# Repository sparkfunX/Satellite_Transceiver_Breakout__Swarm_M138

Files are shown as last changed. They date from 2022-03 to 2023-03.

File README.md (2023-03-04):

# Satellite Transceiver Breakout - Swarm M138

SparkFun Satellite Transceiver Kit - Swarm M138 (https://www.sparkfun.com/products/21287)

[*SparkFun Satellite Transceiver Kit - Swarm M138*](https://www.sparkfun.com/products/21287)

A breakout for the Swarm M138 satellite transceiver.

This breakout allows you to power and communicate with the Swarm M138 using USB 3 or USB-C, or breakout pins.

We've written a Python3 PyQt5 GUI to let you communicate with the modem. You will find it in its own dedicated repo:
- [**SparkFun Swarm M138 GUI**](https://github.com/sparkfun/SparkFun_Swarm_M138_GUI)

You will find the modem manual in the [**Documents**](./Documents) folder. It contains the full list of modem commands and messages.

You can also integrate the satellite transceiver directly into your project; the breakout pads can be used to provide power and access the 3.3V UART TX and RX signals.

Open the two split jumper pads on the bottom of the PCB first, located between the TXO/CH340_RXI and RXI/CH340_TXO pads. Then connect:
* GND to GND on your Arduino board
* VIN to 5V/V_USB on your Arduino board
* TXO to RX on your Arduino board (3.3V only!)
* RXI to TX on your Arduino board (3.3V only!)

Our [Swarm Satellite Arduino Library](https://github.com/sparkfun/SparkFun_Swarm_Satellite_Arduino_Library) makes communicating with the modem really easy.

## Repository Contents

- [**/Hardware**](./Hardware) - contains the Eagle PCB, SCH and LBR design files
- [**/Documents**](./Documents) - contains the datasheet etc. for the Swarm M138
- [**LICENSE.md**](./LICENSE.md) - contains the licence information

<br>

- [**SparkFun Swarm M138 GUI**](https://github.com/sparkfun/SparkFun_Swarm_M138_GUI) - dedicated repo for the Swarm M138 GUI

## Product Versions

- [KIT-21287](https://www.sparkfun.com/products/21287) - SparkFun Satellite Transceiver Kit - Swarm M138
- [SPX-19236](https://www.sparkfun.com/products/19236) - Original SparkX version

## License Information

This product is _**open source**_!

Please review the LICENSE.md file for license information.

If you have any questions or concerns on licensing, please contact technical support on our [SparkFun forums](https://forum.sparkfun.com/viewforum.php?f=123).

Distributed as-is; no warranty is given.

- Your friends at SparkFun.

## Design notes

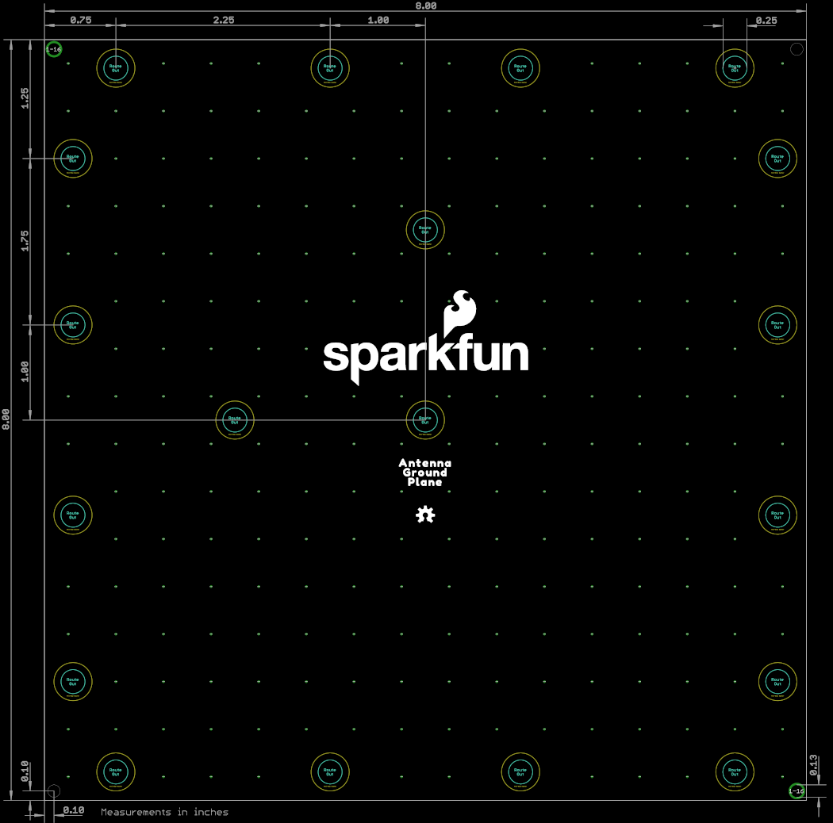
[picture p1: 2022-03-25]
Hardware/Ground Plate/Dimensions.png

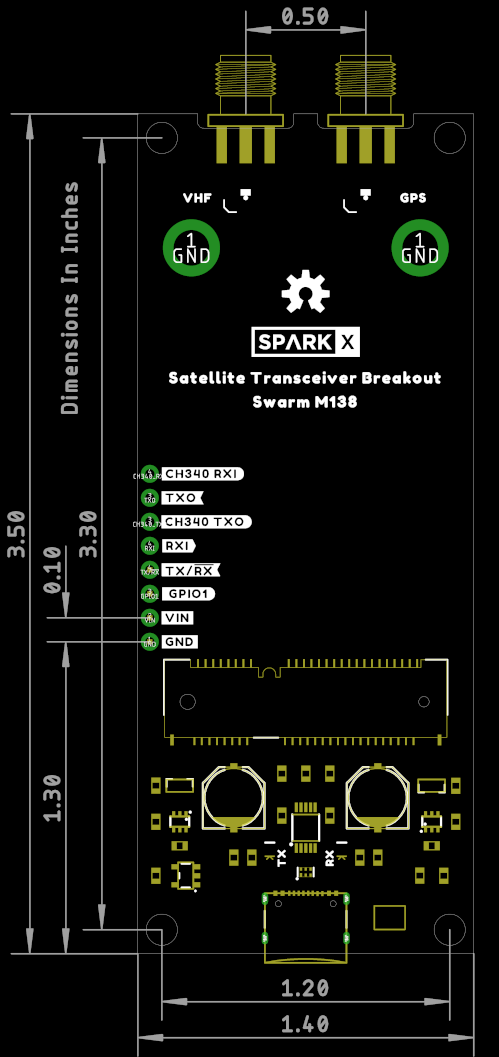
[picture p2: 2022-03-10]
img/Dimensions.png

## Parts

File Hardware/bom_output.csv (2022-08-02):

Qty | PROD_ID | Names | Value | Package
5 | CAP-08604 | C1; C2; C3; C7; C9 | 0.1uF | 0603
2 | CAP-12547 | C4; C5 | 100uF | PANASONIC_D
1 | CAP-11015 | C6 | 10uF | 0603
1 | CAP-13930 | C8 | 1.0uF | 0603
1 | CAP-00867 | C10 | 10nF | 0603
1 | DIO-14084 | D1 | PRTR5V0U2F | SOT886
1 | DIO-00821 | D2 | GREEN | LED-0603
1 | DIO-09003 | D3 | Yellow | LED-0603
1 | CONN-08289 | E1 | VHF | SMA-EDGE
1 | CONN-08289 | E2 | GPS | SMA-EDGE
1 | RES-14313 | F1 | 6V/2A | 1210
2 | CONN-09193 | GPS; VHF | U.FL | U.FL
2 | HW-16629 | H5; H6 | STAND-OFF-REFLOW-M2.5_1.5MM_TALL | STAND-OFF-REFLOW-M2.5
1 | CONN-14122 | J1 |  | USB-C-16P-2LAYER-PADS
1 | CONN-09696 | J2 |  | 1X04_NO_SILK
2 | TRANS-14386 | Q1; Q3 |  | SOT363_PHILIPS
2 | TRANS-14388 | Q2; Q4 | 20V/4.2A/52mΩ/1.4W | SOT23-3
2 | RES-12083 | R1; R2 | 5.1k | 0603
2 | RES-07863 | R3; R4 | 100 | 0603
4 | RES-07828 | R5; R6; R21; R23 | 100k | 0603
2 | RES-07868 | R22; R24 | 1M | 0603
1 | IC-14135 | U1 | CH340E_MSOP10 | MSOP10
1 | CONN-16558 | U2 | SWARM_M138_TRANSCEIVER_MAIN | M.2-SWARM-M138-A
1 | VREG-12457 | U3 | 3.3V | SOT23-5

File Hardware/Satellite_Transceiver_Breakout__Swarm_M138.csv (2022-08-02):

Part | Value | Device | Package | Description | DESIGNER | PROD_ID | REV | SF_ID | VALUE | Device Library | Device Library URN
BYP | JUMPER-SMT_2_NO_SILK | JUMPER-SMT_2_NO_SILK |  | Normally open jumper |  |  |  |  |  | SparkFun-Jumpers
C1 | 0.1uF | 0.1UF-0603-25V-5% |  | 0.1µF ceramic capacitors |  | CAP-08604 |  |  | 0.1uF | SparkFun-Capacitors
C2 | 0.1uF | 0.1UF-0603-25V-5% |  | 0.1µF ceramic capacitors |  | CAP-08604 |  |  | 0.1uF | SparkFun-Capacitors
C3 | 0.1uF | 0.1UF-0603-25V-5% |  | 0.1µF ceramic capacitors |  | CAP-08604 |  |  | 0.1uF | SparkFun-Capacitors
C4 | 100uF | 100UF-POLAR-25V-20%(ELEC) |  | 100µF polarized capacitors |  | CAP-12547 |  |  | 100uF | SparkFun-Capacitors
C5 | 100uF | 100UF-POLAR-25V-20%(ELEC) |  | 100µF polarized capacitors |  | CAP-12547 |  |  | 100uF | SparkFun-Capacitors
C6 | 10uF | 10UF-0603-6.3V-20% |  | 10.0µF ceramic capacitors |  | CAP-11015 |  |  | 10uF | SparkFun-Capacitors
C7 | 0.1uF | 0.1UF-0603-25V-5% |  | 0.1µF ceramic capacitors |  | CAP-08604 |  |  | 0.1uF | SparkFun-Capacitors
C8 | 1.0uF | 1.0UF-0603-16V-10%-X7R |  | 1µF ceramic capacitors |  | CAP-13930 |  |  | 1.0uF | SparkFun-Capacitors
C9 | 0.1uF | 0.1UF-0603-25V-5% |  | 0.1µF ceramic capacitors |  | CAP-08604 |  |  | 0.1uF | SparkFun-Capacitors
C10 | 10nF | 10NF-0603-50V-10% |  | 0.01uF/10nF/10,000pF ceramic capacitors |  | CAP-00867 |  |  | 10nF | SparkFun-Capacitors
D1 | PRTR5V0U2F | PRTR5V0U2F |  | A small ESD protection device. Most commonly used on USB D+/D- signals to protect large, expensive, or especially sensitive USB enabled devices. |  | DIO-14084 |  |  |  | SparkFun-IC-Power
D2 | GREEN | LED-GREEN0603 |  | Green SMD LED |  | DIO-00821 |  |  | GREEN | SparkFun-LED
D3 | Yellow | LED-YELLOW0603 |  | Yellow SMD LED |  | DIO-09003 |  |  | Yellow | SparkFun-LED
E1 | VHF | ANTENNA-SMA-GROUNDEDEDGE_SMA |  | SMA Antenna Connector w/ Ground |  | CONN-08289 |  |  |  | SparkFun-RF
E2 | GPS | ANTENNA-SMA-GROUNDEDEDGE_SMA |  | SMA Antenna Connector w/ Ground |  | CONN-08289 |  |  |  | SparkFun-RF
F1 | 6V/2A | PPTC_6V2A |  | Resettable Fuse PPTC |  | RES-14313 |  |  | 6V/2A | SparkFun-Fuses
FD1 | FIDUCIAL1X2 | FIDUCIAL1X2 |  | Fiducial Alignment Points |  |  |  |  |  | SparkFun-Aesthetics
FD2 | FIDUCIAL1X2 | FIDUCIAL1X2 |  | Fiducial Alignment Points |  |  |  |  |  | SparkFun-Aesthetics
FD3 | FIDUCIAL1X2 | FIDUCIAL1X2 |  | Fiducial Alignment Points |  |  |  |  |  | SparkFun-Aesthetics
FD4 | FIDUCIAL1X2 | FIDUCIAL1X2 |  | Fiducial Alignment Points |  |  |  |  |  | SparkFun-Aesthetics
FRAME1 | FRAME-LEDGER | FRAME-LEDGER |  | Schematic Frame - Ledger |  |  |  |  |  | SparkFun-Aesthetics
GND1 | GND | GND |  | Ground Supply Symbol |  |  |  |  |  | SparkFun-PowerSymbols
GND2 | GND | GND |  | Ground Supply Symbol |  |  |  |  |  | SparkFun-PowerSymbols
GND3 | GND | GND |  | Ground Supply Symbol |  |  |  |  |  | SparkFun-PowerSymbols
GND5 | GND | GND |  | Ground Supply Symbol |  |  |  |  |  | SparkFun-PowerSymbols
GND8 | GND | GND |  | Ground Supply Symbol |  |  |  |  |  | SparkFun-PowerSymbols
GND9 | GND | GND |  | Ground Supply Symbol |  |  |  |  |  | SparkFun-PowerSymbols
GND10 | GND | GND |  | Ground Supply Symbol |  |  |  |  |  | SparkFun-PowerSymbols
GND11 | GND | GND |  | Ground Supply Symbol |  |  |  |  |  | SparkFun-PowerSymbols
GND12 | GND | GND |  | Ground Supply Symbol |  |  |  |  |  | SparkFun-PowerSymbols
GND13 | GND | GND |  | Ground Supply Symbol |  |  |  |  |  | SparkFun-PowerSymbols
GND14 | GND | GND |  | Ground Supply Symbol |  |  |  |  |  | SparkFun-PowerSymbols
GND15 | GND | GND |  | Ground Supply Symbol |  |  |  |  |  | SparkFun-PowerSymbols
GND16 | GND | GND |  | Ground Supply Symbol |  |  |  |  |  | SparkFun-PowerSymbols
GND17 | GND | GND |  | Ground Supply Symbol |  |  |  |  |  | SparkFun-PowerSymbols
GND18 | GND | GND |  | Ground Supply Symbol |  |  |  |  |  | SparkFun-PowerSymbols
GND19 | GND | GND |  | Ground Supply Symbol |  |  |  |  |  | SparkFun-PowerSymbols
GND20 | GND | GND |  | Ground Supply Symbol |  |  |  |  |  | SparkFun-PowerSymbols
GND21 | GND | GND |  | Ground Supply Symbol |  |  |  |  |  | SparkFun-PowerSymbols
GND22 | GND | GND |  | Ground Supply Symbol |  |  |  |  |  | SparkFun-PowerSymbols
GND23 | GND | GND |  | Ground Supply Symbol |  |  |  |  |  | SparkFun-PowerSymbols
GND24 | GND | GND |  | Ground Supply Symbol |  |  |  |  |  | SparkFun-PowerSymbols
GND25 | GND | GND |  | Ground Supply Symbol |  |  |  |  |  | SparkFun-PowerSymbols
GND26 | GND | GND |  | Ground Supply Symbol |  |  |  |  |  | SparkFun-PowerSymbols
GND27 | GND | GND |  | Ground Supply Symbol |  |  |  |  |  | SparkFun-PowerSymbols
GND33 | GND | GND |  | Ground Supply Symbol |  |  |  |  |  | SparkFun-PowerSymbols
GND34 | GND | GND |  | Ground Supply Symbol |  |  |  |  |  | SparkFun-PowerSymbols
GND35 | GND | GND |  | Ground Supply Symbol |  |  |  |  |  | SparkFun-PowerSymbols
GND36 | GND | GND |  | Ground Supply Symbol |  |  |  |  |  | SparkFun-PowerSymbols
GND37 | GND | GND |  | Ground Supply Symbol |  |  |  |  |  | SparkFun-PowerSymbols
GPIO1 | JUMPER-SMT_3_1-NC_TRACE_SILK | JUMPER-SMT_3_1-NC_TRACE_SILK |  | Normally closed trace jumper (1 of 2 connections) |  |  |  |  |  | SparkFun-Jumpers
GPS | U.FL | U.FL2PIN |  | SMD Antenna Connector - U.FL |  | CONN-09193 |  | WRL-09144 | U.FL | SparkFun-Connectors
H1 | STAND-OFF | STAND-OFF |  | Stand Off |  |  |  |  |  | SparkFun-Hardware
H2 | STAND-OFF | STAND-OFF |  | Stand Off |  |  |  |  |  | SparkFun-Hardware
H3 | STAND-OFF | STAND-OFF |  | Stand Off |  |  |  |  |  | SparkFun-Hardware
H4 | STAND-OFF | STAND-OFF |  | Stand Off |  |  |  |  |  | SparkFun-Hardware
H5 | STAND-OFF-REFLOW-M2.5_1.5MM_TALL | STAND-OFF-REFLOW-M2.5_1.5MM_TALL |  | Stand Off Reflow Compatible |  | HW-16629 |  |  |  | SparkFun-Hardware
H6 | STAND-OFF-REFLOW-M2.5_1.5MM_TALL | STAND-OFF-REFLOW-M2.5_1.5MM_TALL |  | Stand Off Reflow Compatible |  | HW-16629 |  |  |  | SparkFun-Hardware
J1 |  | USB_C_2-LAYER_PADS |  | USB Type C 16Pin Connector |  | CONN-14122 |  |  |  | SparkFun-Connectors
J2 |  | CONN_041X04_NO_SILK |  | Multi connection point. Often used as Generic Header-pin footprint for 0.1 inch spaced/style header connections |  | CONN-09696 |  |  |  | SparkFun-Connectors
JP1 | USB_SOLDER_PADS | USB_SOLDER_PADS |  | Solder pad access to USB pins. Helpful to expose on PCBs so user can attach external USB connector if necessary. |  |  |  |  |  | SparkFun-Connectors
LOGO1 | SPECIAL_INSTRUCTIONS-ORDERING | SPECIAL_INSTRUCTIONS-ORDERING |  | Special Ordering/Production Instructions Alert |  |  |  |  |  | SparkFun-Aesthetics
LOGO2 | OSHW-LOGOM | OSHW-LOGOM |  | Open-Source Hardware (OSHW) Logo |  |  |  |  |  | SparkFun-Aesthetics
LOGO3 | OSHW-LOGOM | OSHW-LOGOM |  | Open-Source Hardware (OSHW) Logo |  |  |  |  |  | SparkFun-Aesthetics
Q1 |  | TRANS_PNP_DUALSOT-363 |  | Dual PNP Transistors in Single Package |  | TRANS-14386 |  |  |  | SparkFun-DiscreteSemi
Q2 | 20V/4.2A/52mΩ/1.4W | MOSFET_PCH-DMG2305UX-7 |  | P-channel MOSFETs |  | TRANS-14388 |  |  | 20V/4.2A/52mΩ/1.4W | SparkFun-DiscreteSemi
Q3 |  | TRANS_PNP_DUALSOT-363 |  | Dual PNP Transistors in Single Package |  | TRANS-14386 |  |  |  | SparkFun-DiscreteSemi
Q4 | 20V/4.2A/52mΩ/1.4W | MOSFET_PCH-DMG2305UX-7 |  | P-channel MOSFETs |  | TRANS-14388 |  |  | 20V/4.2A/52mΩ/1.4W | SparkFun-DiscreteSemi
R1 | 5.1k | 5.1KOHM5.1KOHM-0603-1/10W-1% |  |  |  | RES-12083 |  |  | 5.1k | SparkFun-Resistors
R2 | 5.1k | 5.1KOHM5.1KOHM-0603-1/10W-1% |  |  |  | RES-12083 |  |  | 5.1k | SparkFun-Resistors
R3 | 100 | 100OHM-0603-1/10W-1% |  | 100Ω resistor |  | RES-07863 |  |  | 100 | SparkFun-Resistors
R4 | 100 | 100OHM-0603-1/10W-1% |  | 100Ω resistor |  | RES-07863 |  |  | 100 | SparkFun-Resistors
R5 | 100k | 100KOHM-0603-1/10W-1% |  | 100kΩ resistor |  | RES-07828 |  |  | 100k | SparkFun-Resistors
R6 | 100k | 100KOHM-0603-1/10W-1% |  | 100kΩ resistor |  | RES-07828 |  |  | 100k | SparkFun-Resistors
R21 | 100k | 100KOHM-0603-1/10W-1% |  | 100kΩ resistor |  | RES-07828 |  |  | 100k | SparkFun-Resistors
R22 | 1M | 1MOHM-0603-1/4W-5% |  | 1MΩ resistor |  | RES-07868 |  |  | 1M | SparkFun-Resistors
R23 | 100k | 100KOHM-0603-1/10W-1% |  | 100kΩ resistor |  | RES-07828 |  |  | 100k | SparkFun-Resistors
R24 | 1M | 1MOHM-0603-1/4W-5% |  | 1MΩ resistor |  | RES-07868 |  |  | 1M | SparkFun-Resistors
RXI | JUMPER-COMBO_2_NC_TRACE | JUMPER-COMBO_2_NC_TRACE |  |  |  |  |  |  |  | SparkFun-Jumpers
RX_LED | JUMPER-SMT_2_NC_TRACE_SILK | JUMPER-SMT_2_NC_TRACE_SILK |  | Normally closed trace jumper |  |  |  |  |  | SparkFun-Jumpers
SUPPLY1 | V_USB | V_USB |  | USB Voltage Supply |  |  |  |  |  | SparkFun-PowerSymbols
SUPPLY2 | V_USB_2 | V_USB_2 |  | USB Voltage Supply |  |  |  |  |  | SparkFun-PowerSymbols
SUPPLY4 | V_USB_2 | V_USB_2 |  | USB Voltage Supply |  |  |  |  |  | SparkFun-PowerSymbols
SUPPLY5 | VIN | VIN |  | Input Voltage Supply |  |  |  |  |  | SparkFun-PowerSymbols
SUPPLY7 | VIN | VIN |  | Input Voltage Supply |  |  |  |  |  | SparkFun-PowerSymbols
SUPPLY8 | V_USB | V_USB |  | USB Voltage Supply |  |  |  |  |  | SparkFun-PowerSymbols
SUPPLY9 | VCC | VCC |  | VCC Voltage Supply |  |  |  |  |  | SparkFun-PowerSymbols
SUPPLY10 | VCC | VCC |  | VCC Voltage Supply |  |  |  |  |  | SparkFun-PowerSymbols
SUPPLY11 | VCC | VCC |  | VCC Voltage Supply |  |  |  |  |  | SparkFun-PowerSymbols
SUPPLY12 | VCC | VCC |  | VCC Voltage Supply |  |  |  |  |  | SparkFun-PowerSymbols
SUPPLY14 | VCC | VCC |  | VCC Voltage Supply |  |  |  |  |  | SparkFun-PowerSymbols
SUPPLY15 | VCC | VCC |  | VCC Voltage Supply |  |  |  |  |  | SparkFun-PowerSymbols
SUPPLY16 | VIN | VIN |  | Input Voltage Supply |  |  |  |  |  | SparkFun-PowerSymbols
SUPPLY17 | 3.3V | 3.3V |  | 3.3V Supply Symbol |  |  |  |  |  | SparkFun-PowerSymbols
SUPPLY18 | 3.3V | 3.3V |  | 3.3V Supply Symbol |  |  |  |  |  | SparkFun-PowerSymbols
SUPPLY19 | 3.3V | 3.3V |  | 3.3V Supply Symbol |  |  |  |  |  | SparkFun-PowerSymbols
SUPPLY20 | V_USB_2 | V_USB_2 |  | USB Voltage Supply |  |  |  |  |  | SparkFun-PowerSymbols
SUPPLY21 | V_USB_2 | V_USB_2 |  | USB Voltage Supply |  |  |  |  |  | SparkFun-PowerSymbols
SUPPLY27 | VCC | VCC |  | VCC Voltage Supply |  |  |  |  |  | SparkFun-PowerSymbols
SUPPLY29 | VCC | VCC |  | VCC Voltage Supply |  |  |  |  |  | SparkFun-PowerSymbols
SUPPLY31 | VCC | VCC |  | VCC Voltage Supply |  |  |  |  |  | SparkFun-PowerSymbols
TXO | JUMPER-COMBO_2_NC_TRACE | JUMPER-COMBO_2_NC_TRACE |  |  |  |  |  |  |  | SparkFun-Jumpers
TX_LED | JUMPER-SMT_2_NC_TRACE_SILK | JUMPER-SMT_2_NC_TRACE_SILK |  | Normally closed trace jumper |  |  |  |  |  | SparkFun-Jumpers
U$1 | SPARKX-LOGO5 | SPARKX-LOGO5 |  |  |  |  |  |  |  | SparkX
U$2 | SPARKX-LOGO5 | SPARKX-LOGO5 |  |  |  |  |  |  |  | SparkX
U1 | CH340E_MSOP10 | CH340E_MSOP10 |  |  |  | IC-14135 |  |  |  | SparkFun-IC-Comms
U2 | SWARM_M138_TRANSCEIVER_MAIN | SWARM_M138_TRANSCEIVER_MAIN |  | Swarm M138 Modem |  | CONN-16558 |  |  |  | SparkFun-RF
U3 | 3.3V | V_REG_AP2112K-3.3V |  | AP2112 - 600mA CMOS LDO Regulator w/ Enable |  | VREG-12457 |  |  | 3.3V | SparkFun-IC-Power
VCC | TEST-POINT3X5 | TEST-POINT3X5 |  | SparkFun Test Points |  |  |  |  |  | SparkFun-Connectors
VHF | U.FL | U.FL2PIN |  | SMD Antenna Connector - U.FL |  | CONN-09193 |  | WRL-09144 | U.FL | SparkFun-Connectors

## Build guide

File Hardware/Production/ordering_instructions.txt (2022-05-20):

panel size, 158x113mm
PCB thickness, 1.6mm
number of layers, 2
soldermask color, Black
silkscreen color, White
oz copper, 1oz
finish, HASL lead free
stencils, top
pcs per panel, 4
min trace width, 0.1524mm / 0.0060in
min drill size, 0.3000mm / 0.0118in

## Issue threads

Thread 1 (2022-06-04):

Example Sketch Request - 'Live' Data Uplink

K4KDR, 2022-06-04:
The M138 is working spectacularly well - way beyond my expectations.  Thanks to all involved.

The Arduino examples are very helpful.  There are examples on how to transmit static text or hex strings as well as examples on how to perform essentially 'Serial Console' type interactions with the M138.

Would it be possible to see an example that illustrates how the M138 will probably be most commonly used:  to **upload sensor data on a periodic (i.e., once per hour) basis?**   I am referring to analog sensors (air temperature, for example) that would be connected to one of the Arduino's input pins and on a periodic basis, the most current 'live' value uploaded via satellite.

In fact, I have already heard from one person tasked with with monitoring environmental data in an EXTREMELY remote location and naturally he is very interested in your product & the SWARM service.  However, while I already use Arduino devices to uplink that kind of data via other LoRa hats as well as via the local IP network, I'm not clear how to submit a 'live' value on a scheduled basis for upload via the M138. (I realize messages have to be queued, so the telemetry won't be EXACTLY live... just looking to acquire the current value once per hour for submission to the uplink queue)

Thanks in advance for any guidance on this!

-Scott,  K4KDR

PaulZC, 2022-06-04:
Hi Scott,

Assuming you want to send your sensor data in text format, the critical lines of code are these:

https://github.com/sparkfun/SparkFun_Swarm_Satellite_Arduino_Library/blob/b2a912294154c3e5fa0529661527b384e36c3efe/examples/Example14_transmitText/Example14_transmit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

```mySwarm.transmitText``` is the function which adds the message (contained in the ```myMessage``` char array) to the modem's transmit queue.

If you wanted to, you could include the local time or modem time in the message itself (together with your sensor data). That way, you would know the time the readings were taken, rather than the time the message was transmitted / delivered etc..

There are many ways of 'triggering' the transmit once per hour. Using Arduino ```millis()``` is the simplest. The code would look something like:

```
static unsigned long lastTransmit;

if (millis() > (lastTransmit + 3600000)) // Transmit once per hour
{
  lastTransmit = millis(); // Update lastTransmit
  uint64_t id;
  char myMessage[192];
  // Add your own code here to put your sensor readings into myMessage in text format
  // Add a 'null' (zero) to mark the end of the data
  Swarm_M138_Error_e err = mySwarm.transmitText((const char *)myMessage, &id);
  // Do something with id here - with you want to
}
```

Is that the kind of thing you are looking for?

Best wishes,
Paul

K4KDR, 2022-06-04:
Thank you for the reply!

My concern from the examples was that the setting of the upload string was static & then the code just listened for opportunities to transmit when a satellite was heard:

```
void loop()
{
  mySwarm.checkUnsolicitedMsg();
}
```

... so, the analog value could get old and was never updated.   It looks like your new code:

```
if (millis() > (lastTransmit + 3600000)) // Transmit once per hour
{
  lastTransmit = millis(); // Update lastTransmit
  uint64_t id;
  char myMessage[192];
  // Add your own code here to put your sensor readings into myMessage in text format
  // Add a 'null' (zero) to mark the end of the data
  Swarm_M138_Error_e err = mySwarm.transmitText((const char *)myMessage, &id);
  // Do something with id here - if you want to
}
```

... will take care of that nicely.  Can't wait to test it out.  Thanks very much!!

PaulZC, 2022-06-04:
Hi Scott,

The examples are a bit 'cluttered'. My bad...

Let me try and simplify the transmit message process:

As we discussed above, you queue a message for transmission using ```mySwarm.transmitText``` (or ```mySwarm.transmitBinary``` ). Once the message is in the transmit queue, the modem will transmit it on the next satellite pass - without needing any further intervention. All you need to do is keep the modem powered on and awake.

There are two ways to tell if your message has been transmitted. You can:
* Check how many messages are in the transmit queue with ```getUnsentMessageCount```
  * When this returns to zero, you know all messages have been sent
* Or wait for the unsolicited ```$TD SENT``` to arrive
  * A ```$TD SENT``` message is generated each time a message is sent
  * It contains the ```msg_ID``` of the message that has just been sent plus other information about the signal strength etc.

You can manually poll the unsent message count as often as you want to.

If you want to make use of the ```$TD SENT``` message, then you need to:
* Set up a callback for it - with ```setTransmitDataCallback```
* Call ```checkUnsolicitedMsg``` often

The callback is called as soon as ```checkUnsolicitedMsg``` 'intercepts' the ```$TD SENT```.

If you unpick the examples a bit, you will find that they show: how to do things manually; and how to use callbacks to help.

E.g. for the GPS Geospatial Information:
* You can request (poll) the geospatial information manually using [getGeospatialInfo](https://github.com/sparkfun/SparkFun_Swarm_Satellite_Arduino_Library/blob/b2a912294154c3e5fa0529661527b384e36c3efe/examples/Example5_GeospatialInformation/Example5_G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)
* And/or you can:
  * Set up a [callback for the $GN message](https://github.com/sparkfun/SparkFun_Swarm_Satellite_Arduino_Library/blob/b2a912294154c3e5fa0529661527b384e36c3efe/examples/Example5_GeospatialInformation/Example5_G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)
  * Enable [unsolicited $GN messages](https://github.com/sparkfun/SparkFun_Swarm_Satellite_Arduino_Library/blob/b2a912294154c3e5fa0529661527b384e36c3efe/examples/Example5_GeospatialInformation/Example5_G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) at your desired rate/interval
  * Call [checkUnsolicitedMsg](https://github.com/sparkfun/SparkFun_Swarm_Satellite_Arduino_Library/blob/b2a912294154c3e5fa0529661527b384e36c3efe/examples/Example5_GeospatialInformation/Example5_G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) often
  * The [callback](https://github.com/sparkfun/SparkFun_Swarm_Satellite_Arduino_Library/blob/b2a912294154c3e5fa0529661527b384e36c3efe/examples/Example5_GeospatialInformation/Example5_G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) is called when a $GN message arrives

One final piece of advice: once an unsolicited messages is enabled, you have to [un-enable it](https://github.com/sparkfun/SparkFun_Swarm_Satellite_Arduino_Library/blob/b2a912294154c3e5fa0529661527b384e36c3efe/examples/Example18_DisableUnsolicitedMessages/Exam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) to stop it being produced. The modem remembers which unsolicited messages are enabled, even when power-cycled. The only one you cannot disable is ```$TD SENT```.

Have fun!
Paul

K4KDR, 2022-06-05:
Thanks again for all the help - much appreciated!!

An update:  https://twitter.com/scott23192/status/1533526372768960512

PaulZC, 2022-06-09:
Linking this to issue 21 in the Library repo. That's also a request for a data uplink example:

https://github.com/sparkfun/SparkFun_Swarm_Satellite_Arduino_Library/issues/21

Closed 2022-06-04.

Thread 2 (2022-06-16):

5v Logic Tolerance?

K4KDR, 2022-06-16:
Since I have to think that I won't be the last person to make this mistake, a question please...

Wanting to test 'Sleep' Mode with the Arduino device connected to my M138, I found that the Arduino Due that I had was not supported by the same **avr/sleep.h** library that is most commonly used.  So, I purchased a couple of MEGA boards to use with the M138 to allow me to experiment with Sleep mode.

However, for several minutes after connecting one of the hardware serial UART connections from the MEGA to the M138, I forgot about the M138's requirement for 3.3v logic levels.  During that time, a message was queued and things appeared to work normally.  However, I immediately disconnected power from both devices and am in the process of wiring up a logic level shifter board between the MEGA & the M138.

Does the M138 have (I hope) "some" tolerance to the presence of a 5v logic level on the serial RX/TX pins?    Fingers crossed that all is well when I re-wire with the 5v/3.3v level shifter in place.

Thanks!

-Scott,  K4KDR

PaulZC, 2022-06-16:
Hi Scott,

This is (probably) a case of "you've got away with it". It is normal for microcontrollers to have protection diodes on their IO pins. If the pin voltage is taken above VCC (3.3V) the diode starts dumping current from the pin to the VCC rail. They're there to cope with brief over-voltage (ESD-like) events. Also the IO (UART) pins on the MEGA will only be able to deliver limited current. Put those two things together and your're _**probably**_ OK.

Proper level-shifters are the best way to go.

I don't know what the quiescent current draw of the MEGA board will be with the processor in sleep. It is probably still quite high. There's a bunch of stuff on there that will keep drawing current even if the processor isn't. If you really want to get the sleep current right down, you need a board that has been designed for it. Our [OpenLog Artemis](https://www.sparkfun.com/products/19426) was designed that way. Take a look at Unexpected Maker's boards too - he's doing great things with the sleep current.

Best wishes,
Paul

PaulZC, 2022-06-16:
Closing...

K4KDR, 2022-06-16:
Thanks so much for the VERY informative reply!   I will certainly check out those other boards.

Yes, now that everything is powered back up with level shifters on all connections, everything seems fine.  Serial Monitor feedback is all correct & messages are uploading via satellite.

Thanks again!

Closed 2022-06-16.

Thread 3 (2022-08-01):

BOM

tremmert81, 2022-08-01:
Is it possible for you to upload the BOM?  I am not finding anything in this repository..

PaulZC, 2022-08-02:
Hi @tremmert81 ,

If you download the free version of Eagle, you can open the hardware files and create the BOM for yourself. But - to save you some time - I've added a couple of different versions to the [Hardware folder](https://github.com/sparkfunX/Satellite_Transceiver_Breakout__Swarm_M138/tree/main/Hardware).

Best wishes,
Paul

Closed 2022-08-02.

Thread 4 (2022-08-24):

M138 Absolute VCC

jacky4566, 2022-08-24:
What is the absolute VCC for the M138?
The datasheet says 5.0V and SparkFun schematic shows this connected directly to USB which is allowed to deviate up to 5.5V

Could be a problem?

PaulZC, 2022-08-25:
Hello Jackson (@jacky4566 ),

The latest M138 datasheet quotes an input voltage of 3.0V to 5.0V. It also quotes absolute limits of 3.0V to 5.0V, which is unusual.

However, an earlier version of the datasheet - the one we were working from when we designed the board - quoted an input voltage range and absolute limits of 3.0V to 5.5V.

I believe the USB voltage requirement is 5.0V +/- 5%. I.e. 5.25V maximum? I believe the +0.5V deviation only applies during transitions (i.e. at switch-on)?

In summary, I believe we're OK, but I will check.

Best wishes,
Paul

PaulZC, 2022-08-26:
Hi Jackson,

We've been in touch with Swarm and they've confirmed that the modem can withstand 5.5V, as an _absolute_ maximum (non-continuous). Regular operation should be between 3.0V and 5.0V.

Best wishes,
Paul

Closed 2022-08-26.

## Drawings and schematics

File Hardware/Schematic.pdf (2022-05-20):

# VBUS CC1 D+D- CC2 SHLD

## Design by: USB⁻C

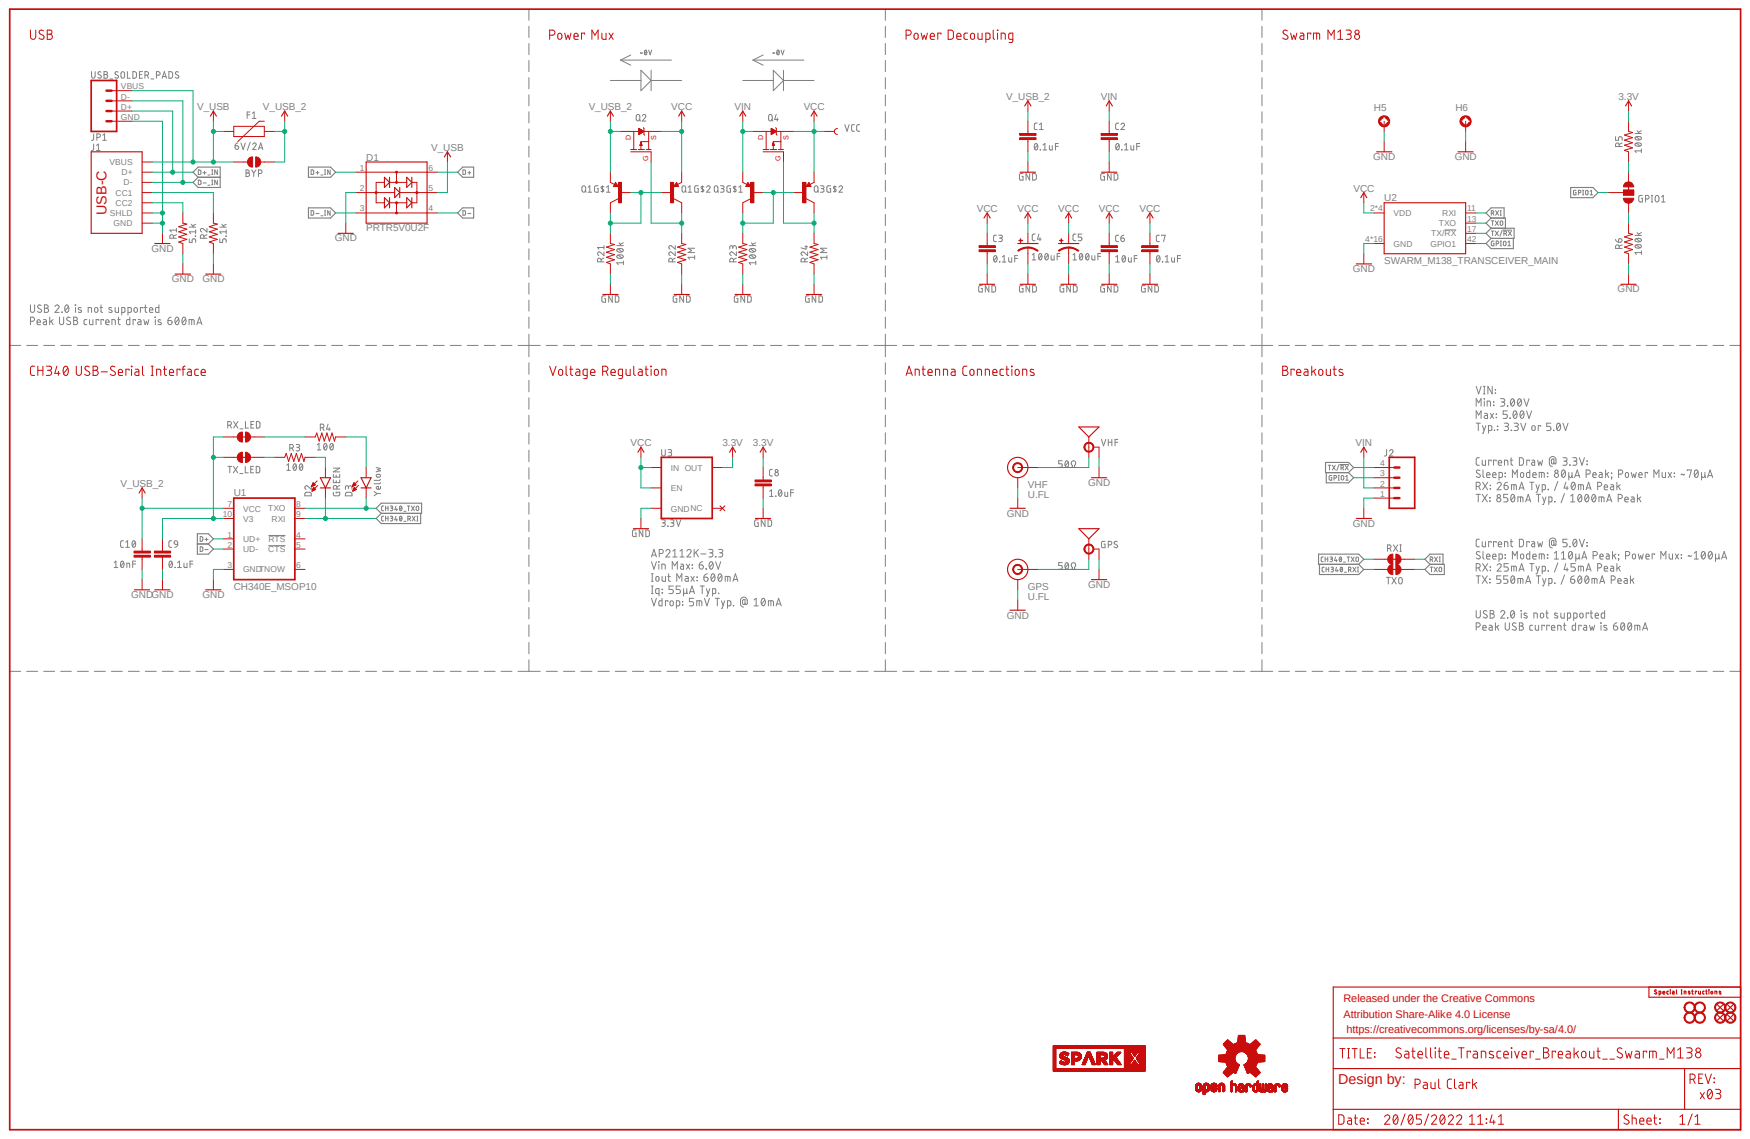
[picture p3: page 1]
GND GND; GND; PRTR5V0U2F; V_USB; VCC; CH340E_MSOP10 GNDGND; VIN; SWARM_M138_TRANSCEIVER_MAIN; V_USB_2; V_USB_2 GND; CTS; 5 RTS; 4 GND 3; TNOW; 6 RXI; 9 TXO; VCC 7 U1; VHF GPS; H6 GND 4*16 VDD 2*4; RXI 11 TX/RX 17 TXO 13 GPIO1 42 U2; INGNDOUT EN; VBUS D- D+GND

GND
U.FL U.FL GND

Released under the Creative Commons
Attribution Share-Alike 4.0 License
https://creativecommons.org/licenses/by-sa/4.0/

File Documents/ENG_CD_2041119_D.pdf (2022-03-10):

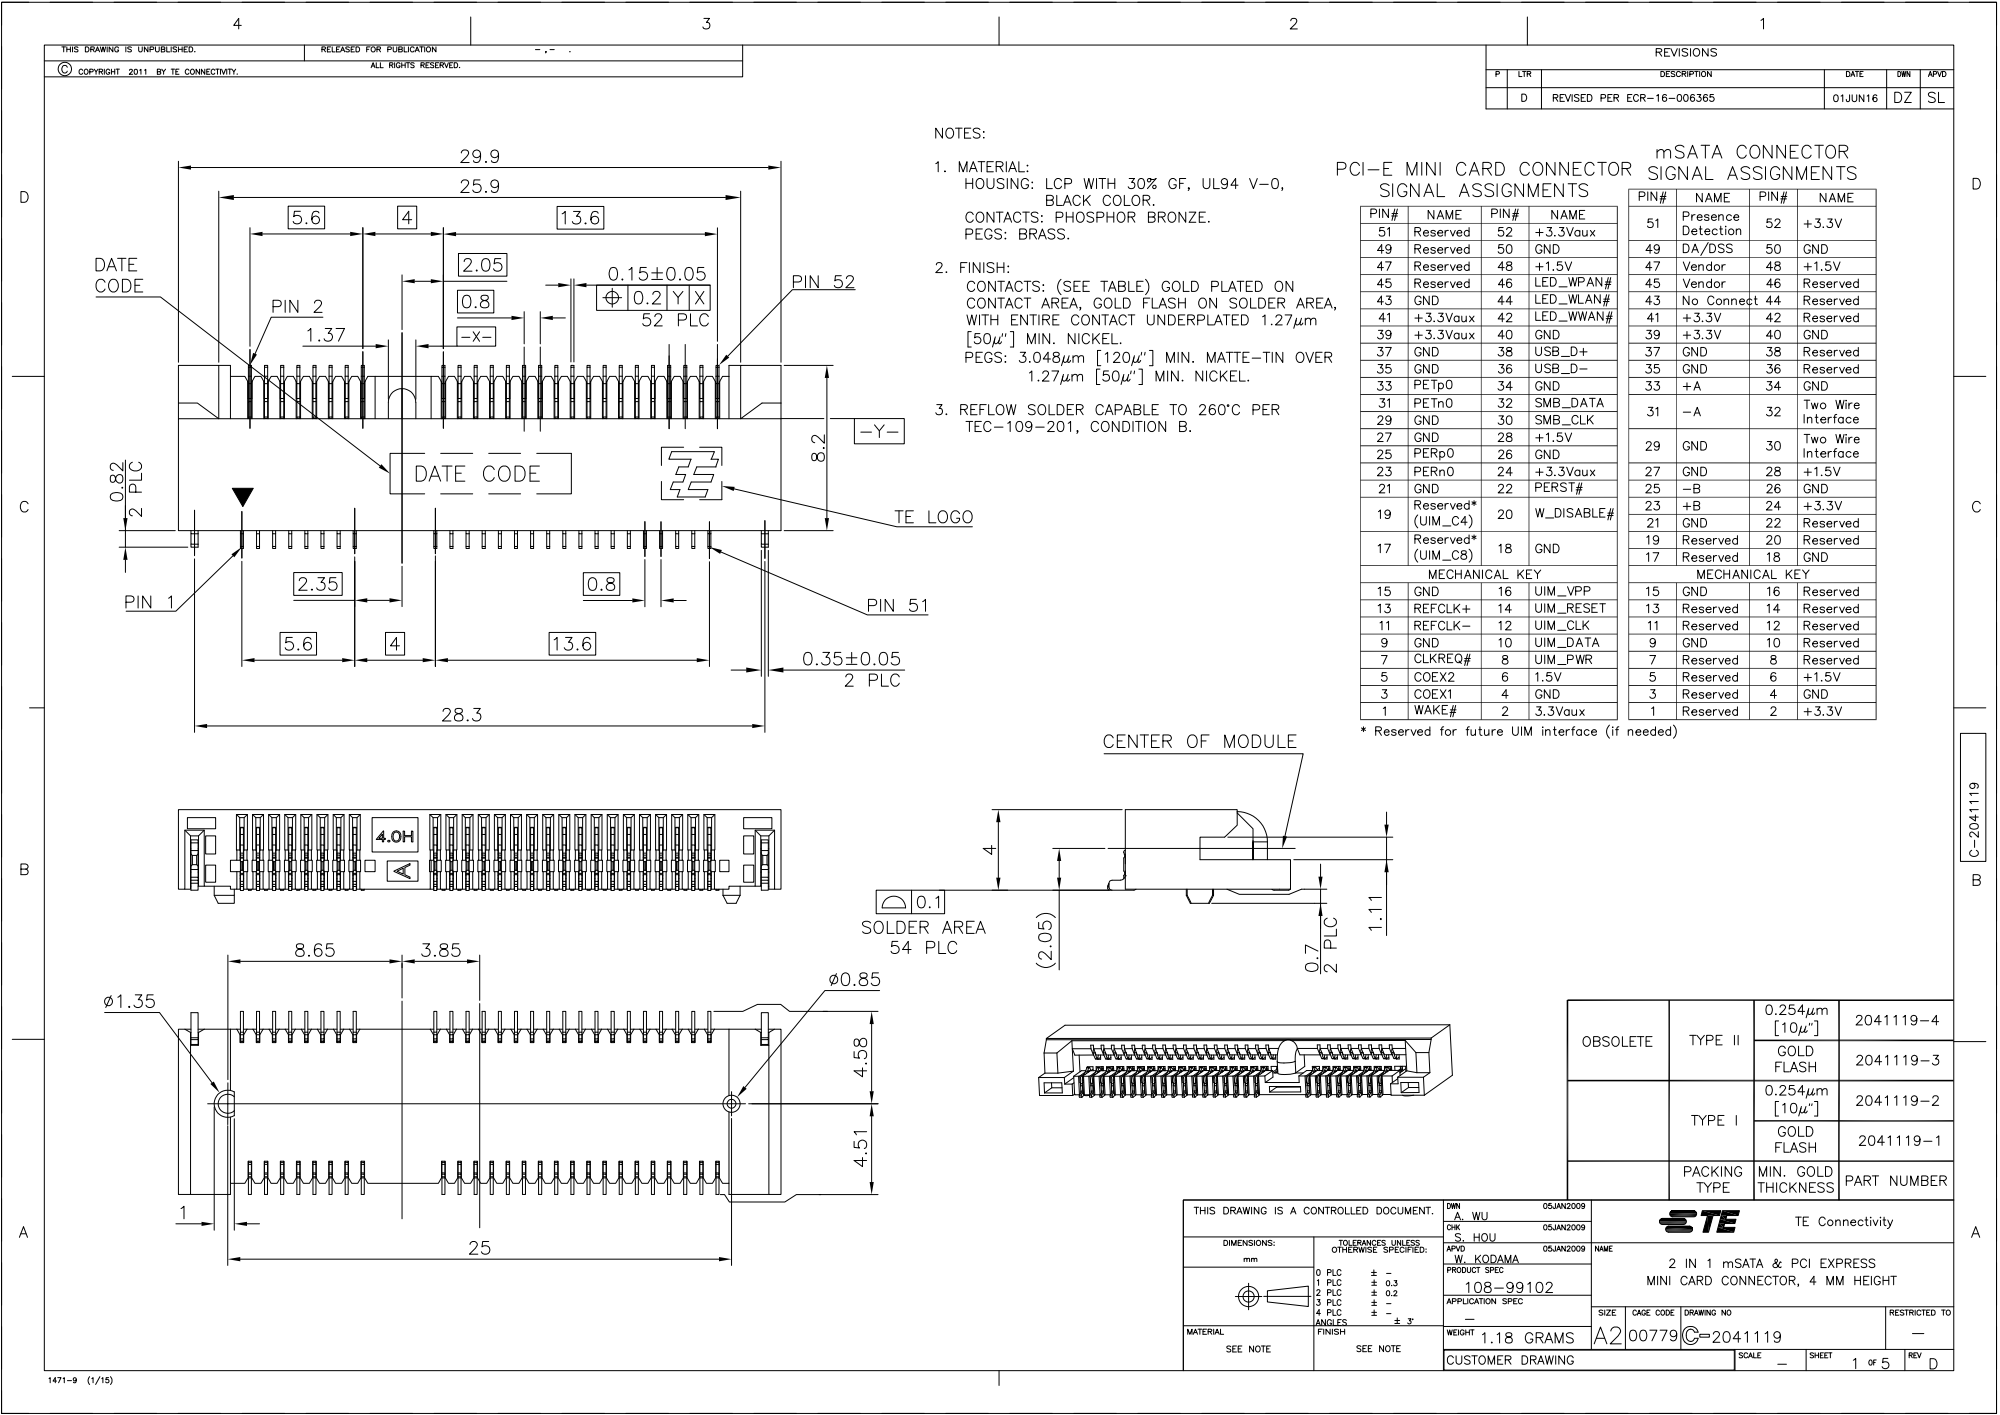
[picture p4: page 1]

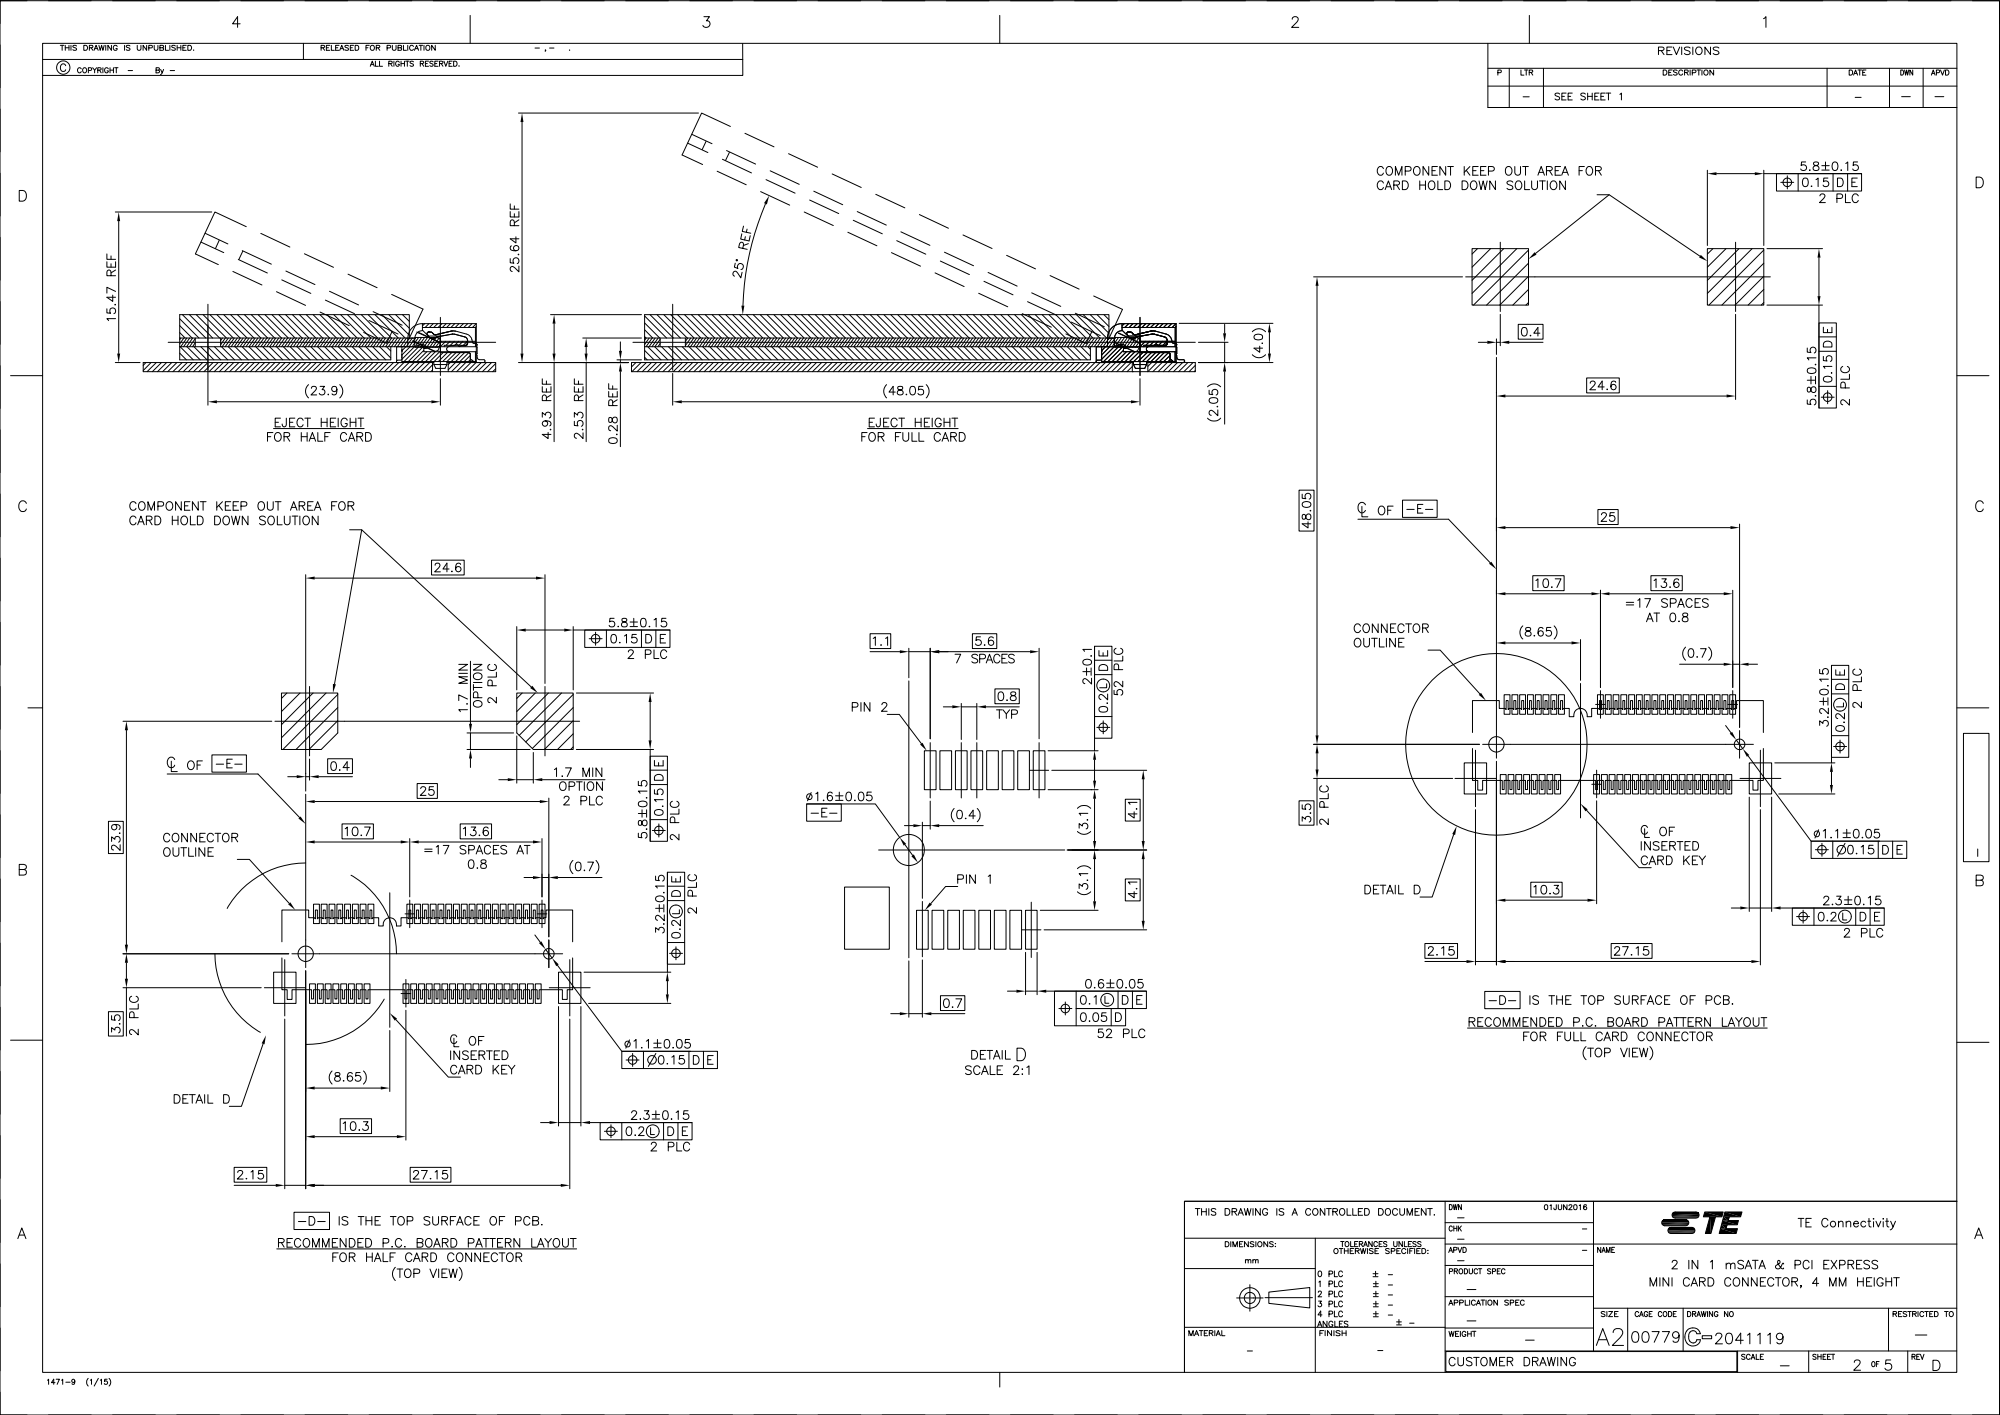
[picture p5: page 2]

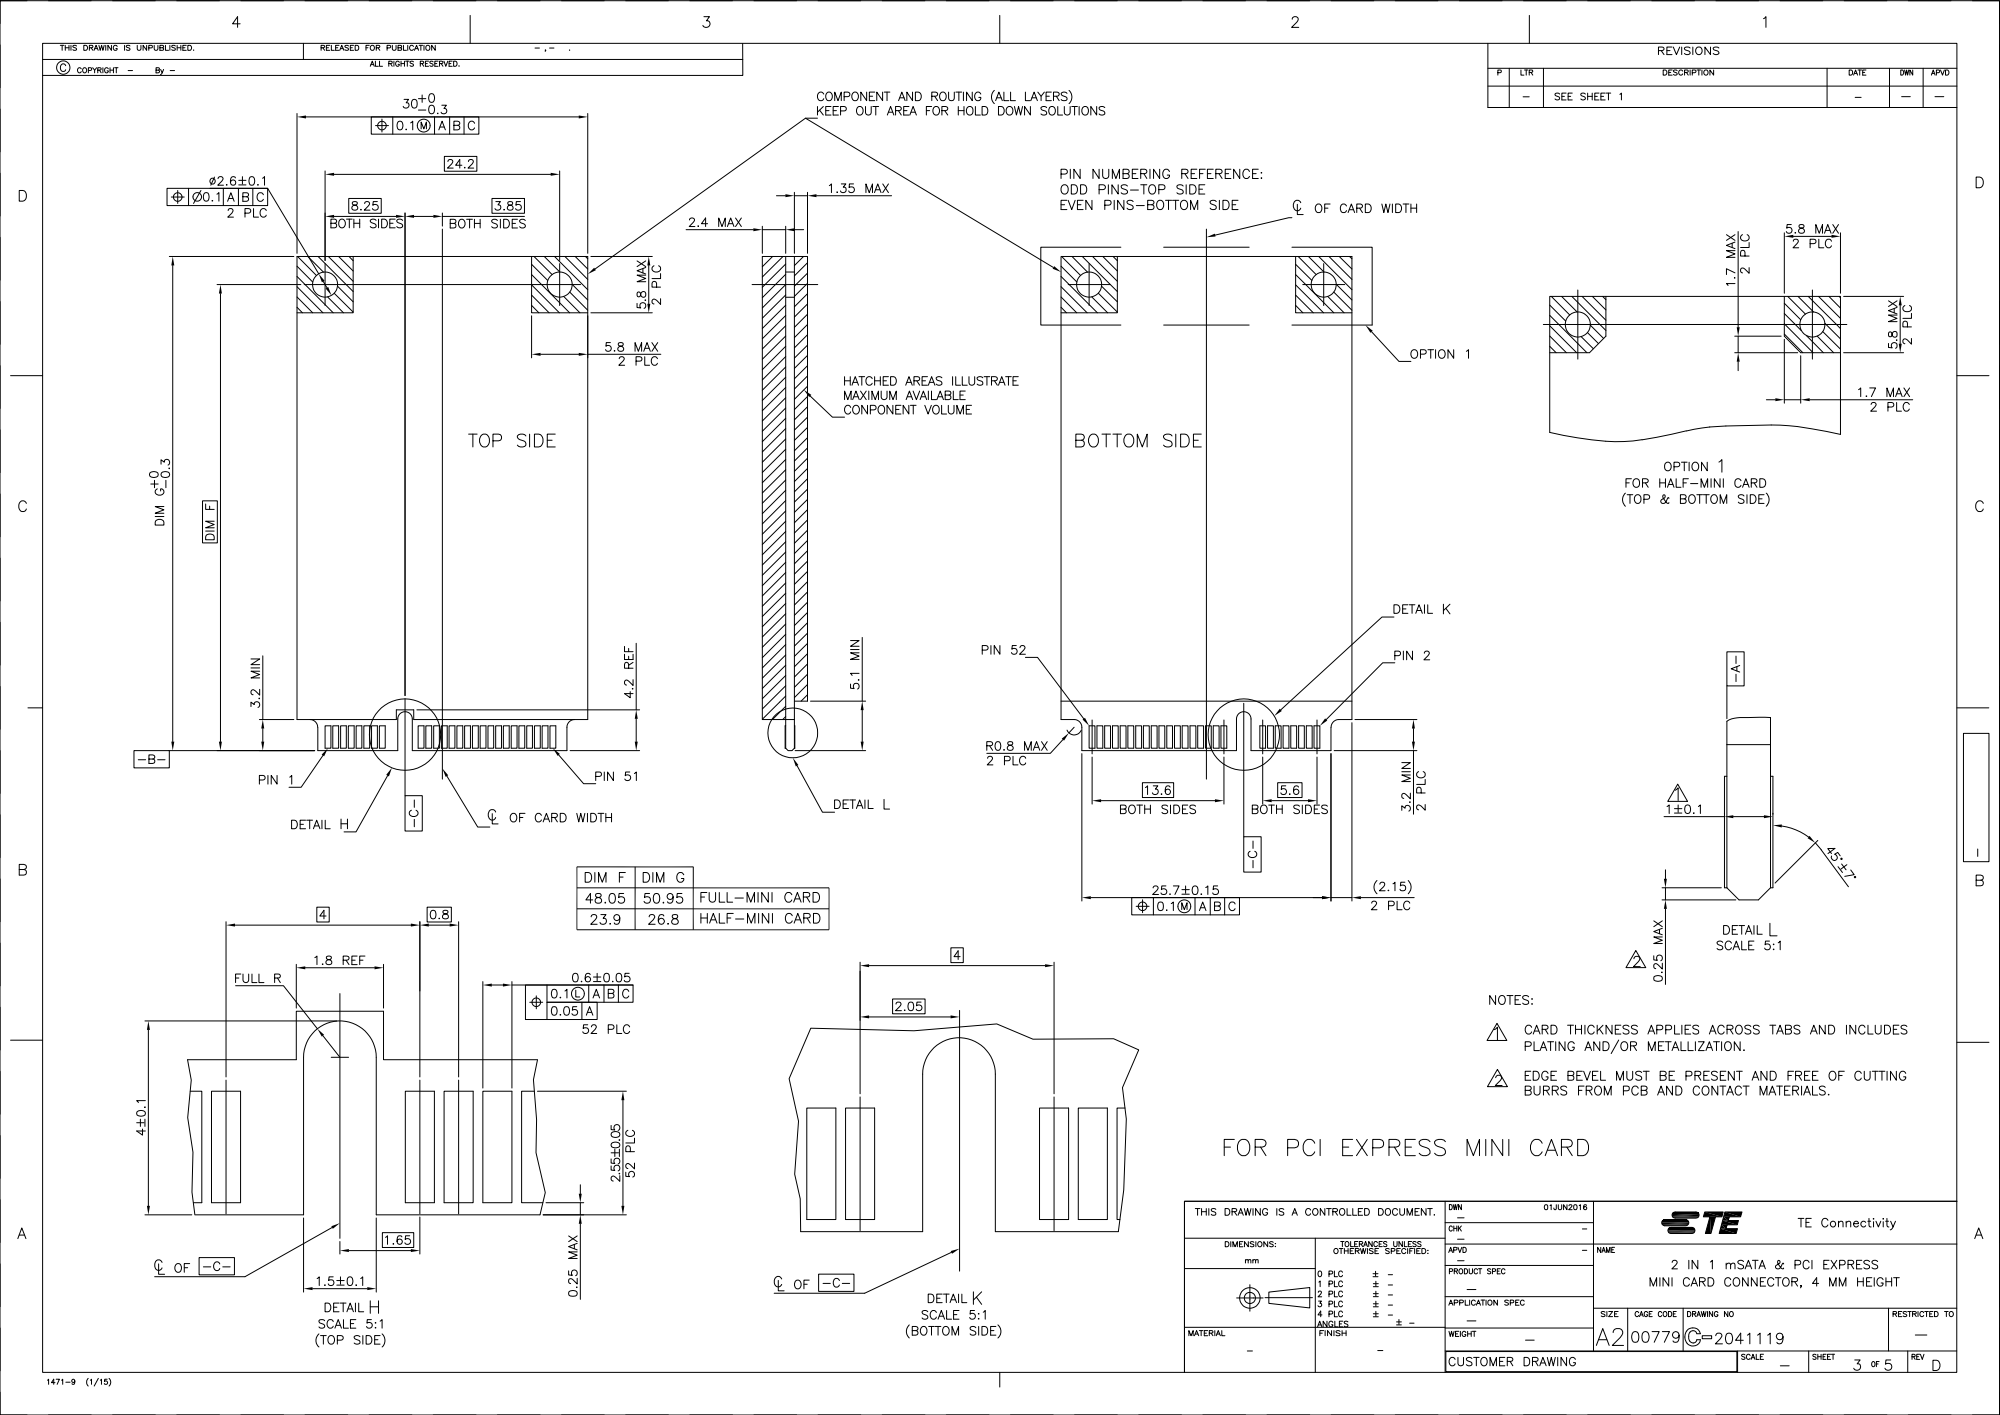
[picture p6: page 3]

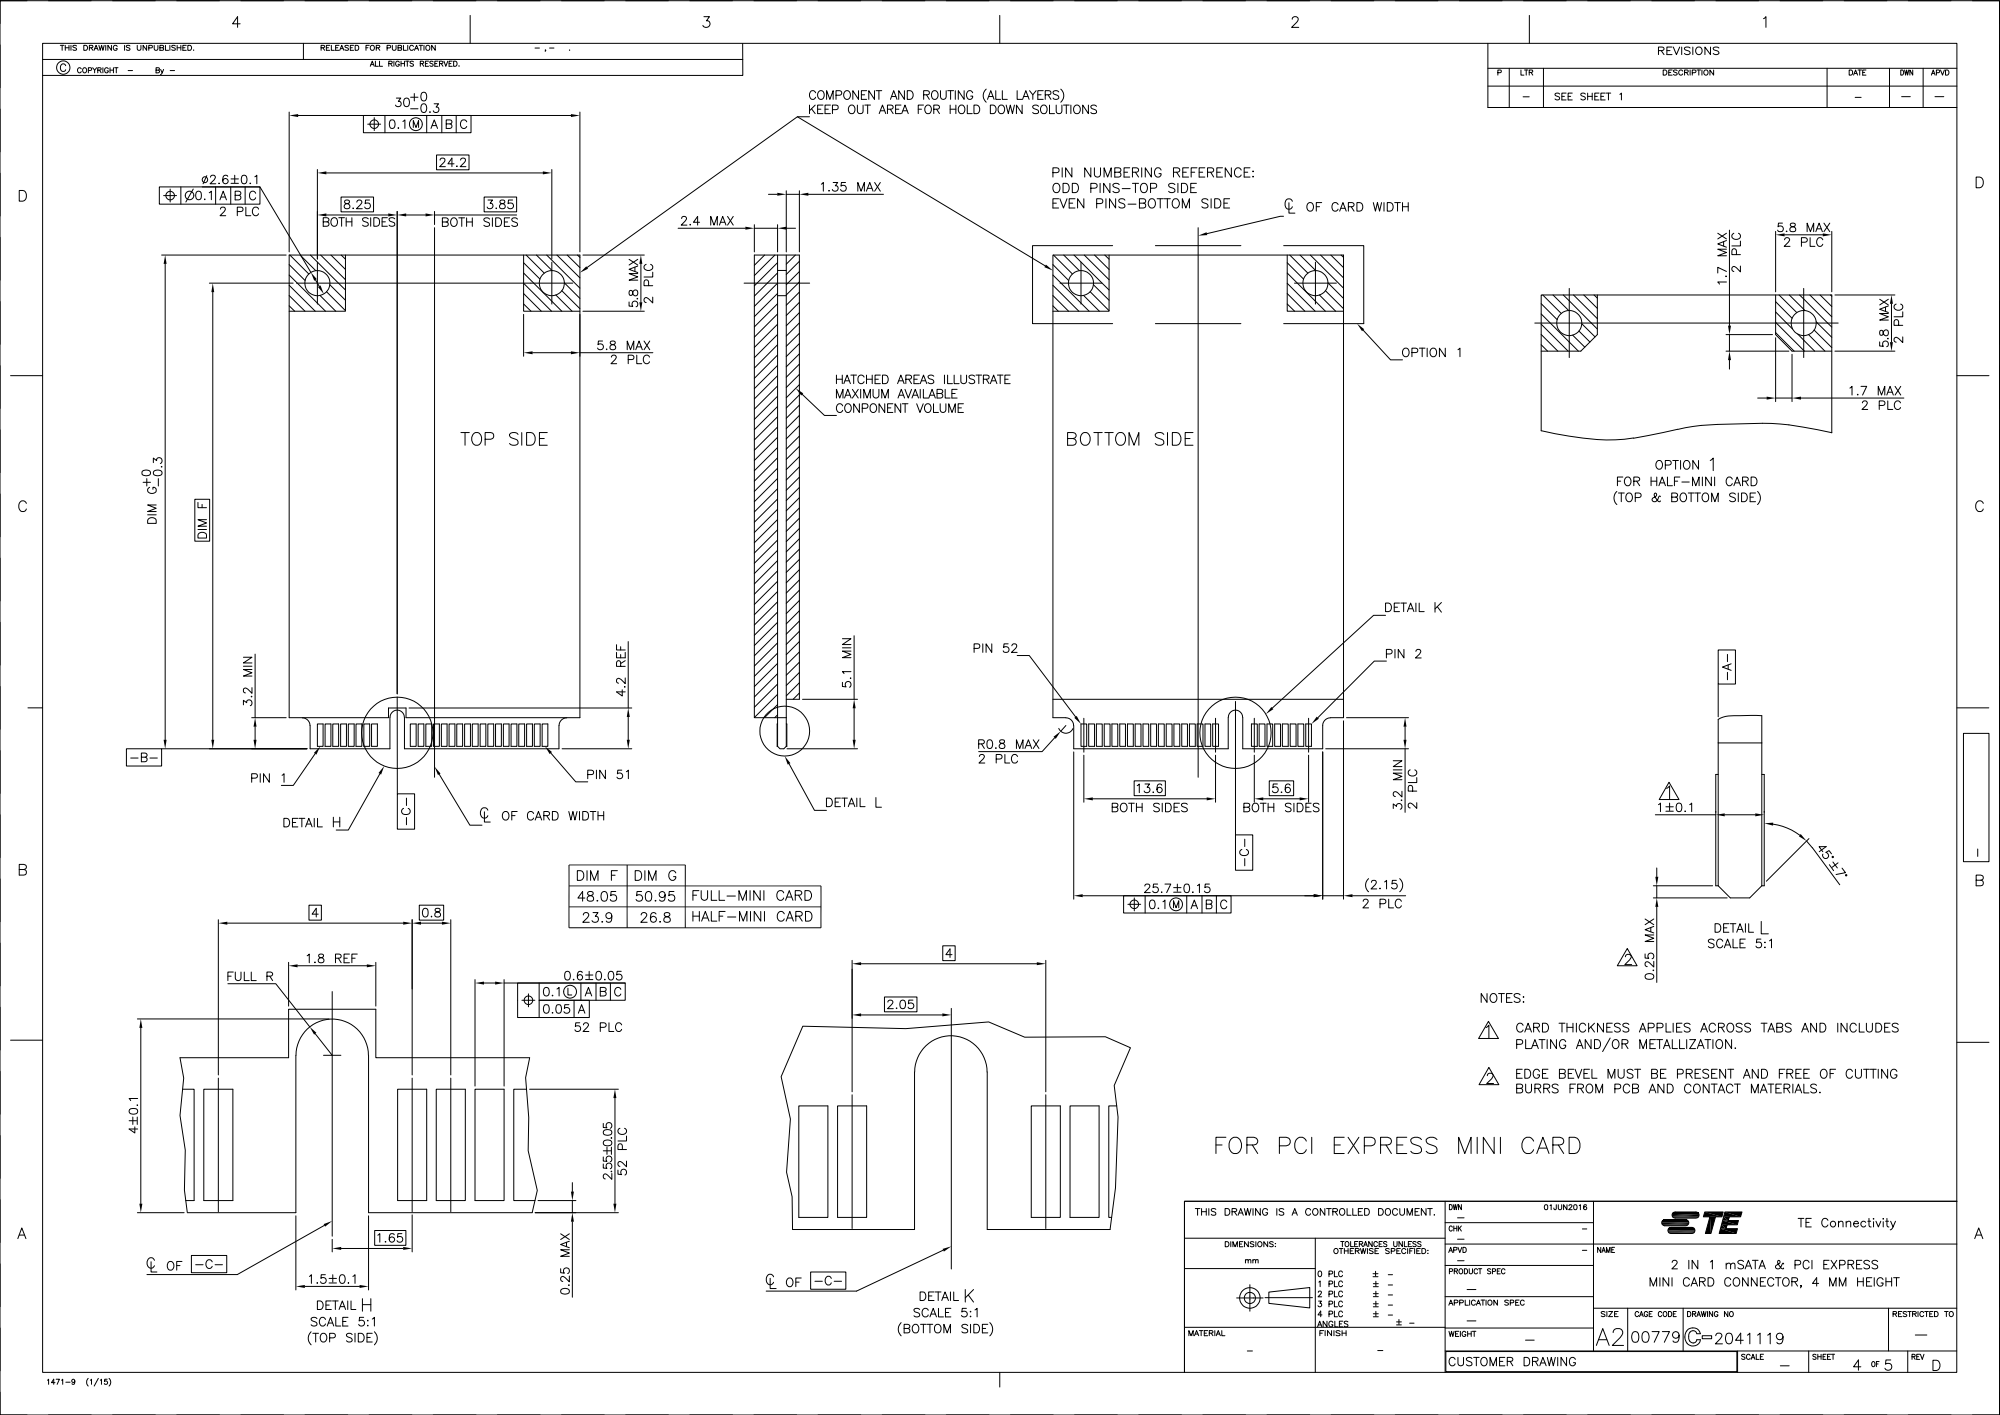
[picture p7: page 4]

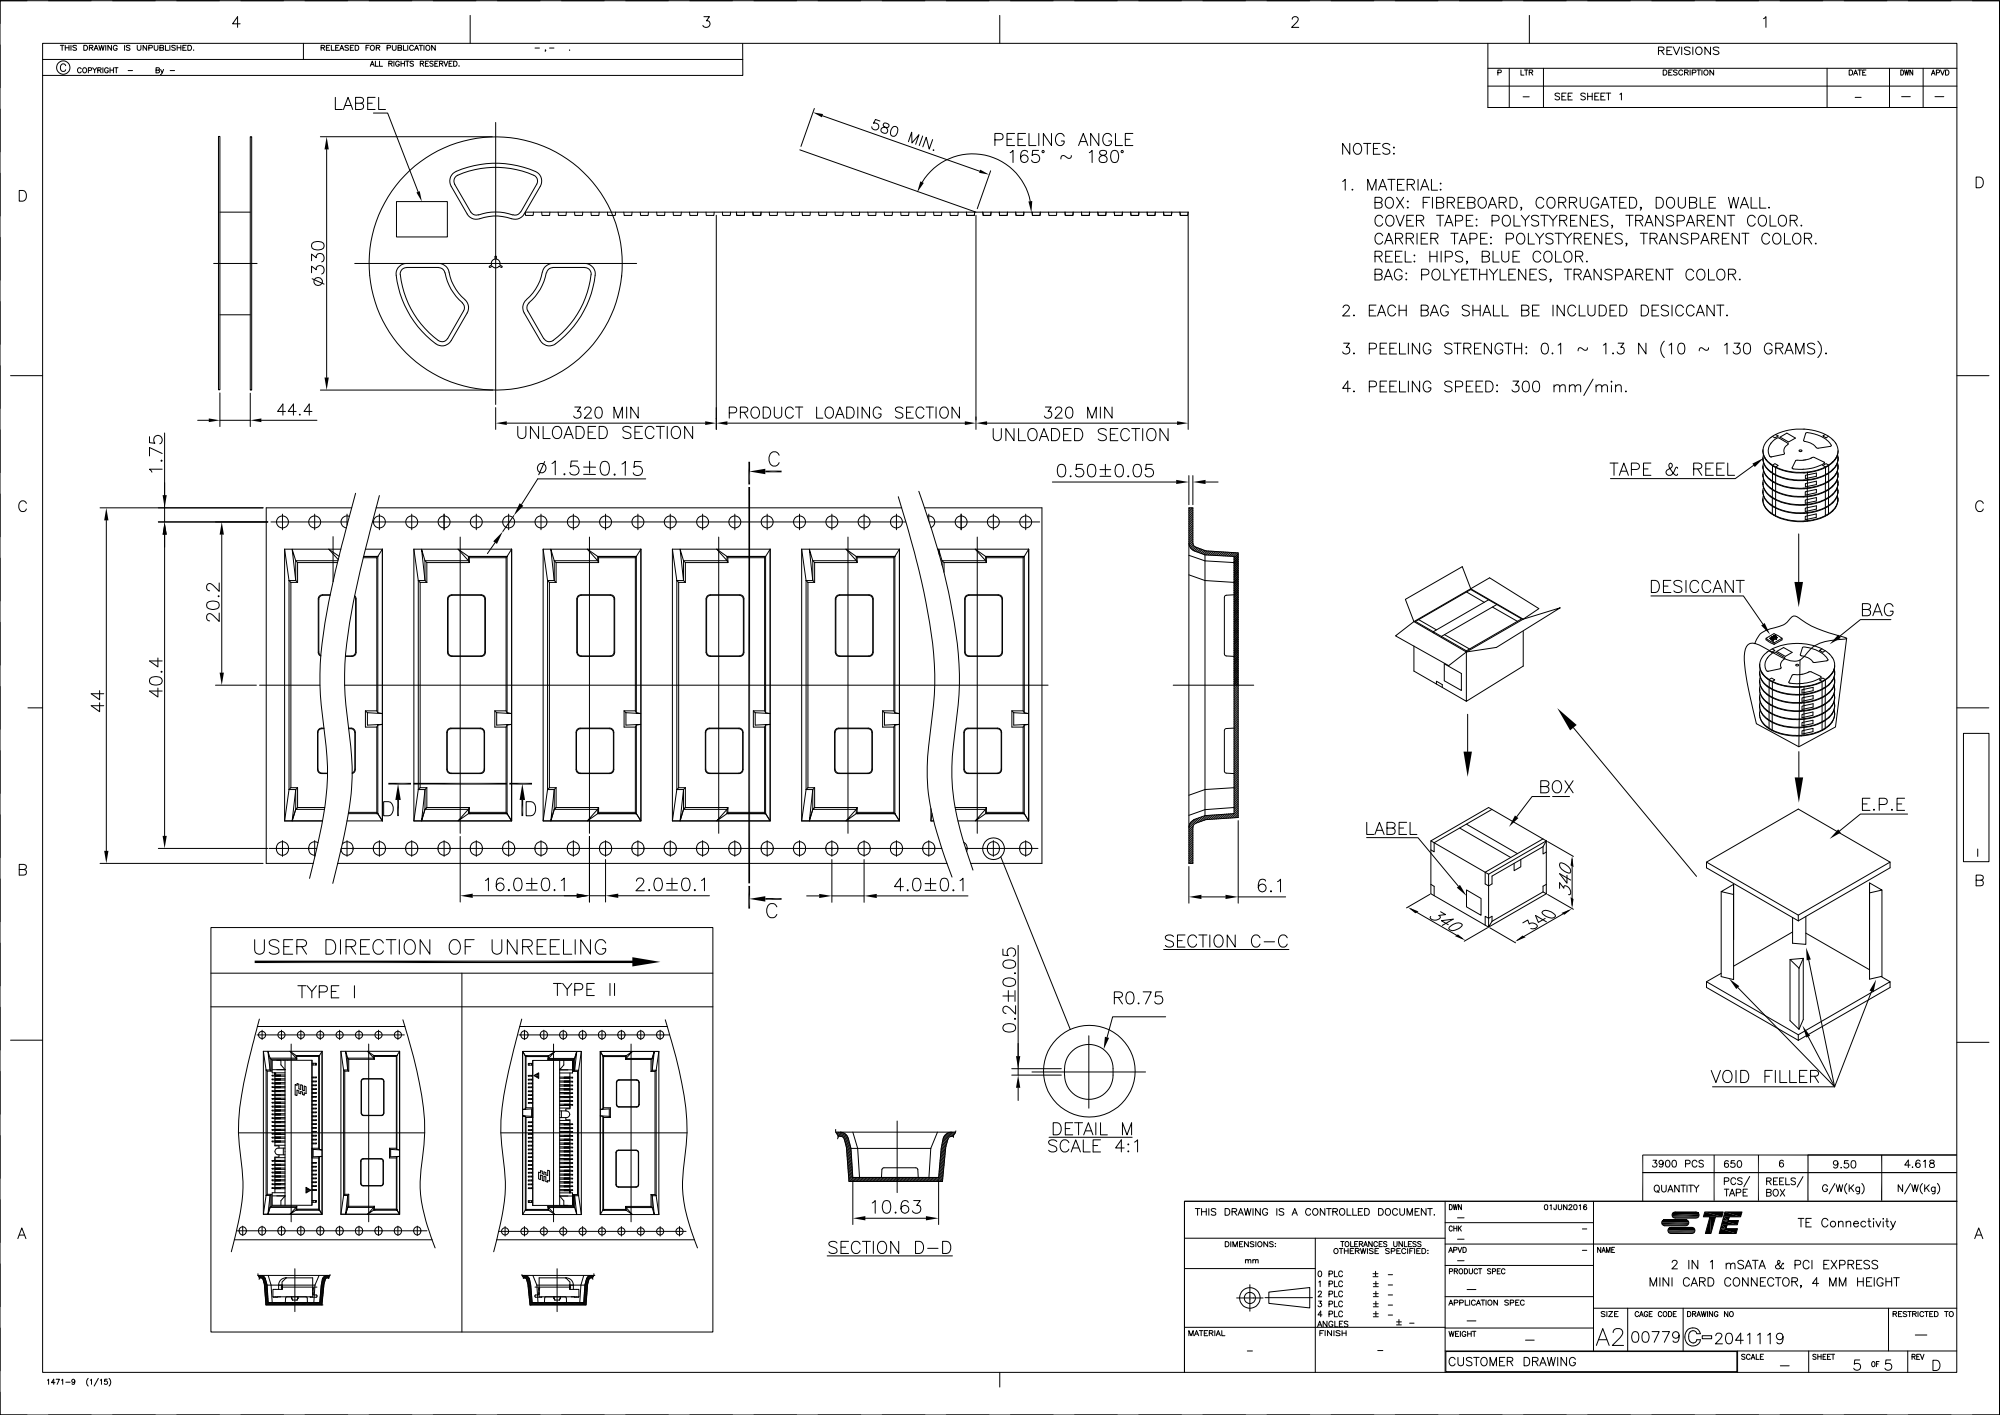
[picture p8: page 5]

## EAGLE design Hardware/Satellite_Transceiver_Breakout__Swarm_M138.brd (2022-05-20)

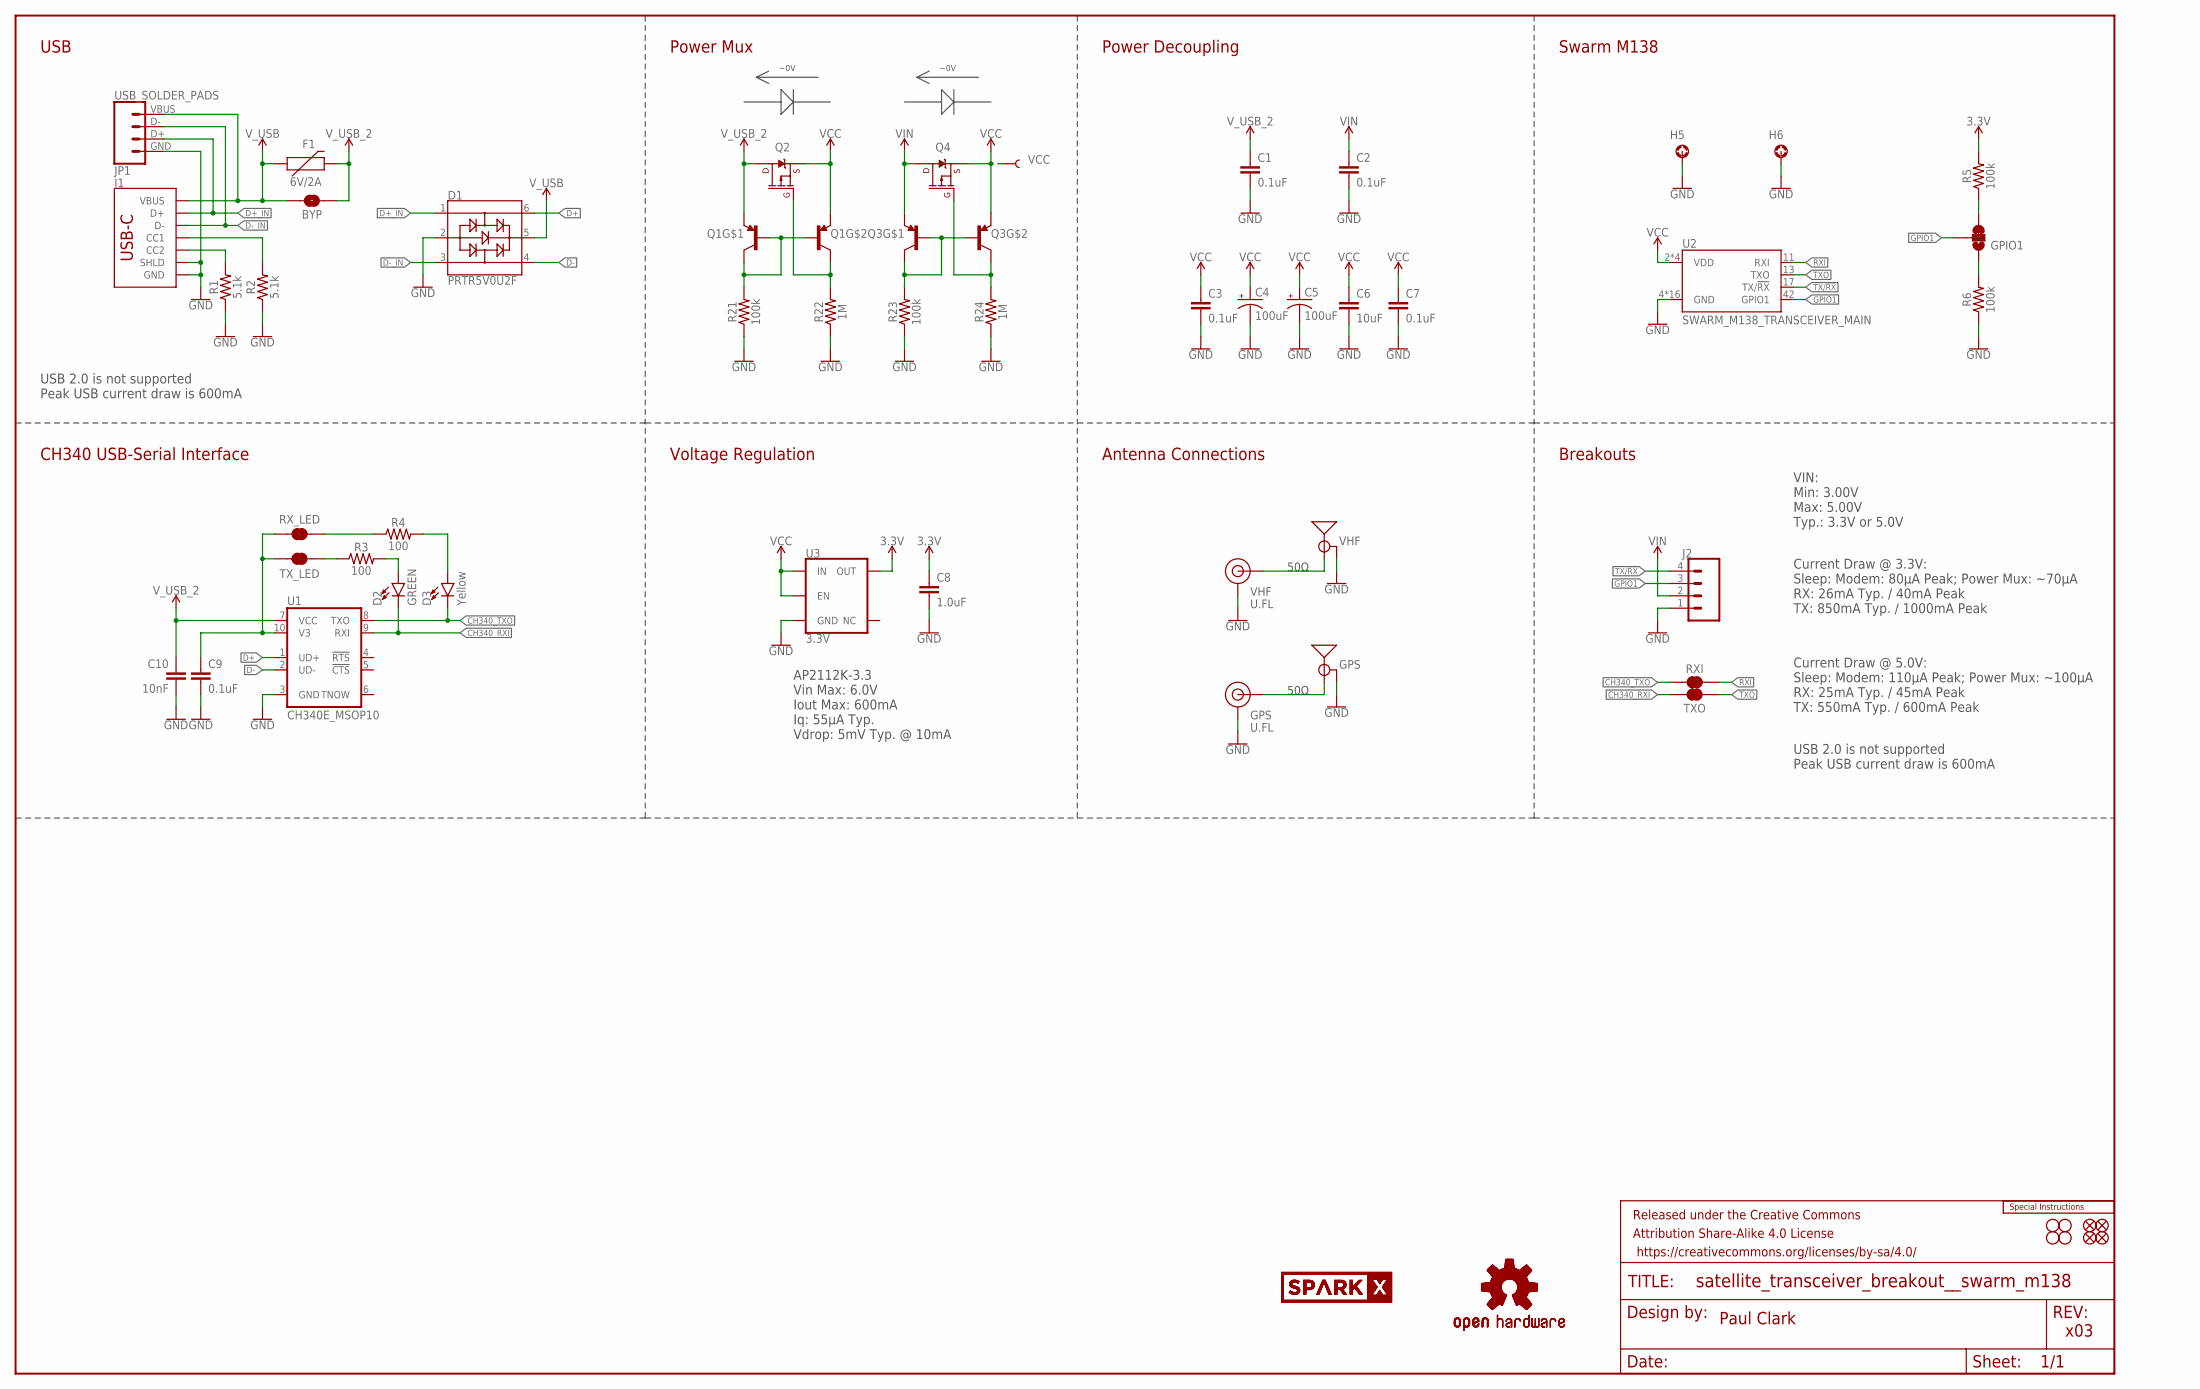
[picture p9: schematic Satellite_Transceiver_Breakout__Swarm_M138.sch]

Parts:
BYP: JUMPER-SMT_2_NO_SILK; SMT-JUMPER_2_NO_SILK
C1, C2, C3, C7, C9: 0.1uF; 0603
C4, C5: 100uF; PANASONIC_D
C6: 10uF; 0603
C8: 1.0uF; 0603
C10: 10nF; 0603
D1: PRTR5V0U2F; SOT886
D2: GREEN; LED-0603
D3: Yellow; LED-0603
E1: VHF; SMA-EDGE
E2: GPS; SMA-EDGE
F1: 6V/2A; 1210
FD1, FD2, FD3, FD4: FIDUCIAL1X2; FIDUCIAL-1X2
FRAME1: FRAME-LEDGER; CREATIVE_COMMONS
GPIO1: JUMPER-SMT_3_1-NC_TRACE_SILK; SMT-JUMPER_3_1-NC_TRACE_SILK
GPS: U.FL
H1, H2, H3, H4: STAND-OFF
H5, H6: STAND-OFF-REFLOW-M2.5_1.5MM_TALL; STAND-OFF-REFLOW-M2.5
J1: USB_C_2-LAYER_PADS; USB-C-16P-2LAYER-PADS
J2: CONN_041X04_NO_SILK; 1X04_NO_SILK
JP1: USB_SOLDER_PADS; USB-SOLDER-PADS
LOGO1: SPECIAL_INSTRUCTIONS-ORDERING; ORDERING_INSTRUCTIONS
LOGO2, LOGO3: OSHW-LOGOM; OSHW-LOGO-M
Q1, Q3: TRANS_PNP_DUALSOT-363; SOT363_PHILIPS
Q2, Q4: 20V/4.2A/52mΩ/1.4W; SOT23-3
R1, R2: 5.1k; 0603
R3, R4: 100; 0603
R5, R6, R21, R23: 100k; 0603
R22, R24: 1M; 0603
RXI: JUMPER-COMBO_2_NC_TRACE; COMBO-JUMPER_2_NC_TRACE
RX_LED: JUMPER-SMT_2_NC_TRACE_SILK; SMT-JUMPER_2_NC_TRACE_SILK
TXO: JUMPER-COMBO_2_NC_TRACE; COMBO-JUMPER_2_NC_TRACE
TX_LED: JUMPER-SMT_2_NC_TRACE_SILK; SMT-JUMPER_2_NC_TRACE_SILK
U1: CH340E_MSOP10; MSOP10
U2: SWARM_M138_TRANSCEIVER_MAIN; M.2-SWARM-M138-A
U3: 3.3V; SOT23-5
U$1, U$2: SPARKX-LOGO5; SPARKX-LARGE
VCC: TEST-POINT3X5; PAD.03X.05
VHF: U.FL

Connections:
3.3V: C8.1, R5.2, U3.5 (OUT)
CH340_RXI: D2.C, TXO.2, TXO.4 (2), U1.9 (RXI)
CH340_TXO: D3.C, RXI.1, RXI.3 (1), U1.8 (TXO)
D+: D1.6, U1.1 (UD+)
D+_IN: D1.1, J1.A6 (D+), J1.B6 (D+), JP1.D+ (3)
D-: D1.4, U1.2 (UD-)
D-_IN: D1.3, J1.A7 (D-), J1.B7 (D-), JP1.D- (2)
GND: C1.2, C2.2, C3.2, C4.-, C5.-, C6.2, C7.2, C8.2, C9.2, C10.2, D1.2, E1.GND@0 (GND), E1.GND@1 (GND), E1.GND@2 (GND), E1.GND@3 (GND), E2.GND@0 (GND), E2.GND@1 (GND), E2.GND@2 (GND), E2.GND@3 (GND), GPS.1 (GND), GPS.2 (GND), H5.1, H6.1, J1.GND, J1.GND2 (GND), J1.SHLD1 (SHLD), J1.SHLD2 (SHLD), J1.SHLD3 (SHLD), J1.SHLD4 (SHLD), J2.1, JP1.GND (4), R1.1, R2.1, R6.1, R21.1, R22.1, R23.1, R24.1, U1.3 (GND), U2.4 (GND), U2.9 (GND), U2.15 (GND), U2.18 (GND), U2.21 (GND), U2.26 (GND), U2.27 (GND), U2.29 (GND), U2.34 (GND), U2.35 (GND), U2.37 (GND), U2.40 (GND), U2.43 (GND), U2.50 (GND), U2.A1 (GND), U2.A2 (GND), U3.2 (GND), VHF.1 (GND), VHF.2 (GND)
GPIO1: GPIO1.2, J2.3, U2.42 (GPIO1)
GPS: E2.SIG (SIGNAL), GPS.FEED (SIGNAL)
unnamed: J1.B5 (CC2), R1.2
unnamed: J1.A5 (CC1), R2.2
unnamed: Q1.2 (B), Q1.5 (B), Q1.6 (C), R21.2
unnamed: C9.1, RX_LED.1, TX_LED.2, U1.10 (V3)
unnamed: R4.1, RX_LED.2
unnamed: D2.A, R3.2
unnamed: D3.A, R4.2
unnamed: R3.1, TX_LED.1
unnamed: Q1.3 (C), Q2.1 (G), R22.2
unnamed: GPIO1.3, R5.1
unnamed: Q3.2 (B), Q3.5 (B), Q3.6 (C), R23.2
unnamed: GPIO1.1, R6.2
unnamed: Q3.3 (C), Q4.1 (G), R24.2
RXI: RXI.2, RXI.4 (2), U2.11 (RXI)
TX/!RX!: J2.4, U2.17 (TX/!RX!)
TXO: TXO.1, TXO.3 (1), U2.13 (TXO)
VCC: C3.1, C4.+, C5.+, C6.1, C7.1, Q1.4 (E), Q2.2 (S), Q3.4 (E), Q4.2 (S), U2.2 (VDD), U2.39 (VDD), U2.41 (VDD), U2.52 (VDD), U3.1 (IN), U3.3 (EN), VCC.1
VHF: E1.SIG (SIGNAL), VHF.FEED (SIGNAL)
VIN: C2.1, J2.2, Q3.1 (E), Q4.3 (D)
V_USB: BYP.2, D1.5, F1.1, J1.VBUS1 (VBUS), J1.VBUS2 (VBUS), JP1.VBUS (1)
V_USB_2: BYP.1, C1.1, C10.1, F1.2, Q1.1 (E), Q2.3 (D), U1.7 (VCC)

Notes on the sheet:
x03
Paul Clark
USB
Power Mux
~0V
Power Decoupling
CH340 USB-Serial Interface
Swarm M138
Antenna Connections
50Ω
Breakouts
VIN: Min: 3.00V Max: 5.00V Typ.: 3.3V or 5.0V
Current Draw @ 3.3V: Sleep: Modem: 80µA Peak; Power Mux: ~70µA RX: 26mA Typ. / 40mA Peak TX: 850mA Typ. / 1000mA Peak
Current Draw @ 5.0V: Sleep: Modem: 110µA Peak; Power Mux: ~100µA RX: 25mA Typ. / 45mA Peak TX: 550mA Typ. / 600mA Peak
USB 2.0 is not supported Peak USB current draw is 600mA
Voltage Regulation
AP2112K-3.3 Vin Max: 6.0V Iout Max: 600mA Iq: 55µA Typ. Vdrop: 5mV Typ. @ 10mA

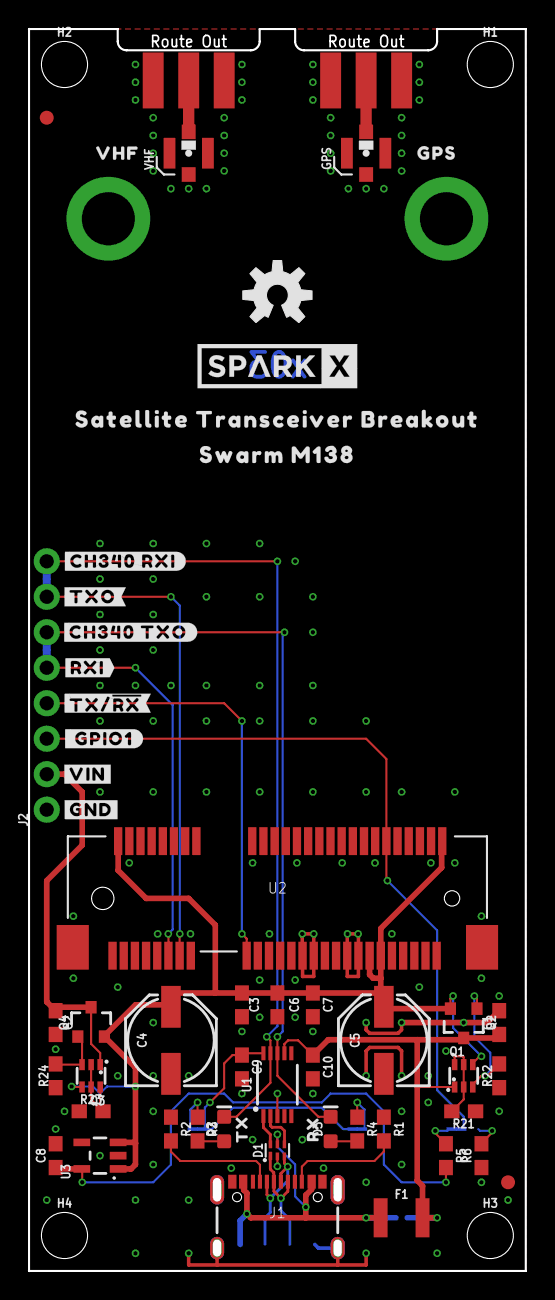
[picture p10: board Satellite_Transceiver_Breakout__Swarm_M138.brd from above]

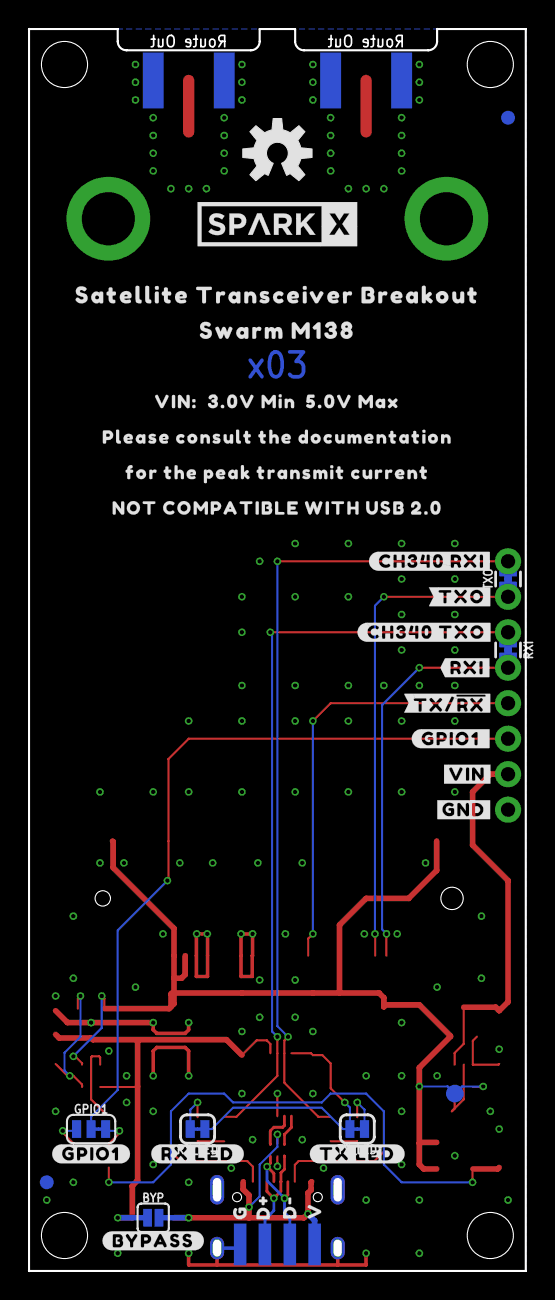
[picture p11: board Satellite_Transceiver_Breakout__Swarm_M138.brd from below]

Board: 2 copper layers, 35.6 x 88.9 mm, 97 parts (34 on the bottom side), 31 nets.

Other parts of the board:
U$3: VHF0
U$4: GPS0
U$5: VIN#__3#0V_MIN__5#0V_MAX0
U$6: PLEASE_CONSULT_THE_DOCUMENTATION0
U$7: #CH340_RXI#0
U$8: #CH340_RXI#341
U$9: #TXO#341
U$10: #TXO#342
U$11: #CH340_TXO#0
U$12: #CH340_TXO#341
U$13: #RXI#0
U$14: #RXI#1
U$15: #TX##RX##1
U$16: #TX##RX##0
U$17: #GPIO1_#2
U$18: V0
U$19: #GPIO1#0
U$20: #_GPIO1#2
U$21, U$22: #VIN#0
U$23, U$24: #GND#0
U$25: TX0
U$26: RX0
U$27: #TX_LED#0
U$28: #RX_LED#0
U$29: #BYPASS#0
U$30: G3
U$31: FOR_THE_PEAK_TRANSMIT_CURRENT1
U$32: NOT_COMPATIBLE_WITH_USB_2#02
U$34, U$39: SATELLITE_TRANSCEIVER_BREAKOUT0
U$36: D#2
U$37: D#1
U$40, U$41: SWARM_M1381

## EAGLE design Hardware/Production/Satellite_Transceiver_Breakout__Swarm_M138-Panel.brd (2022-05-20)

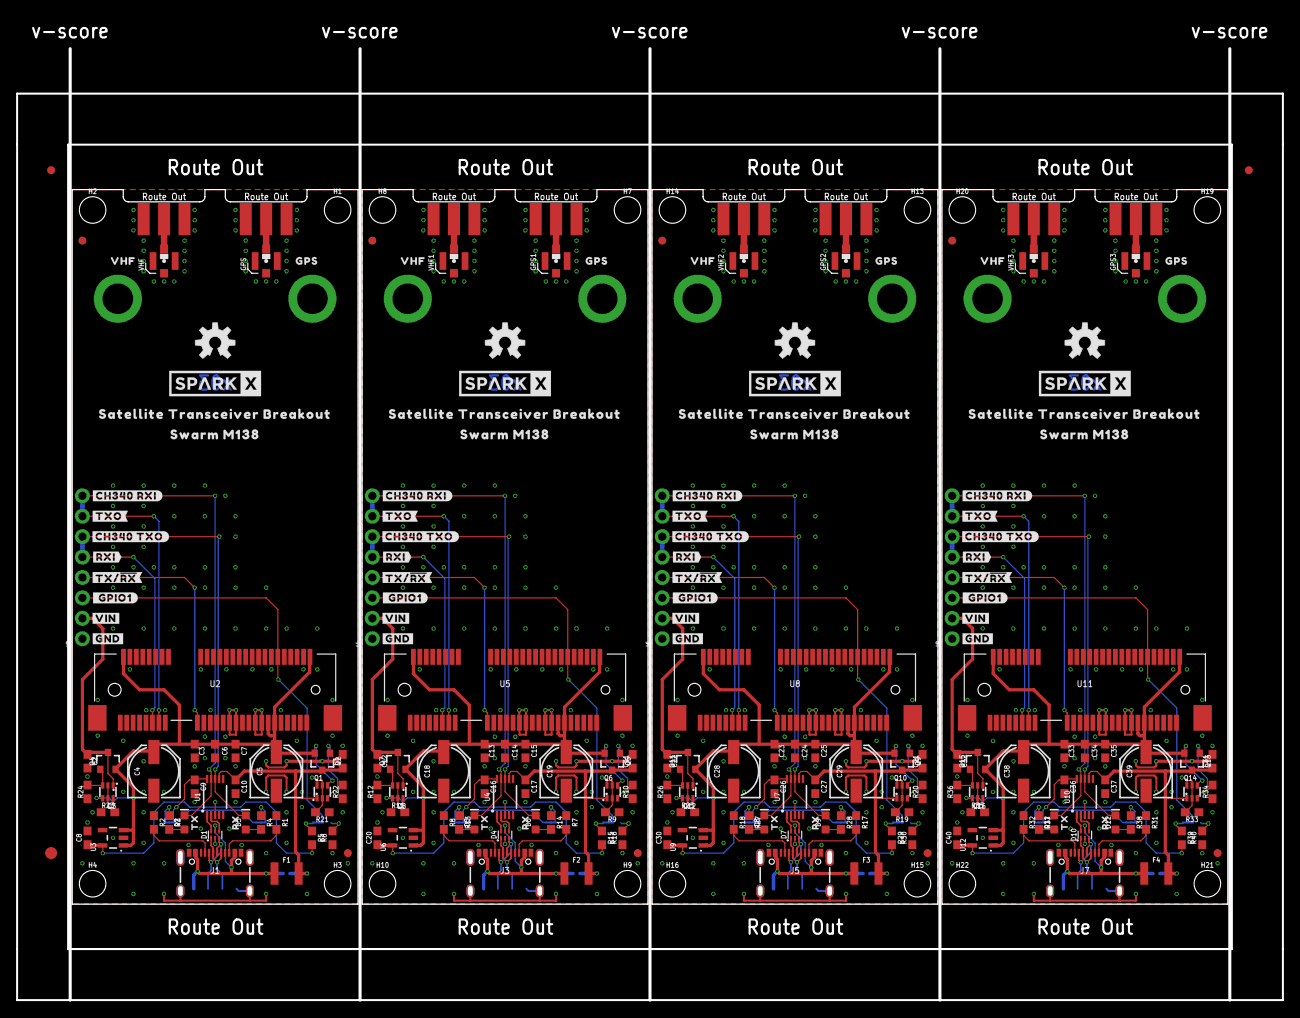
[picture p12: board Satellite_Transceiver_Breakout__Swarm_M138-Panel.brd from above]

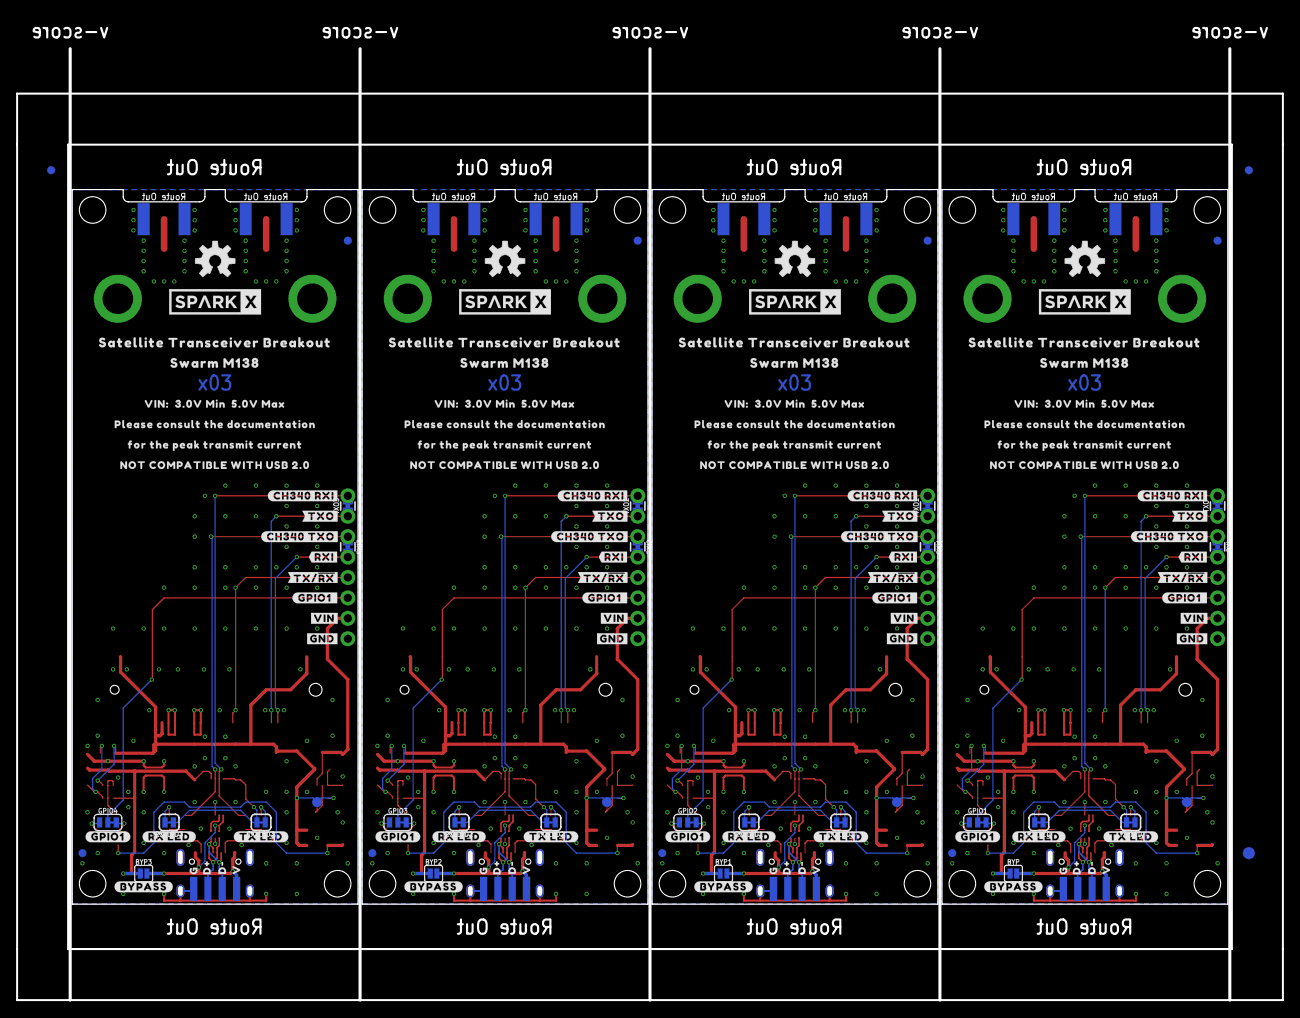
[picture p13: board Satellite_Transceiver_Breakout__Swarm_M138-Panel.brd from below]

Board: 2 copper layers, 157.5 x 118.4 mm, 386 parts (139 on the bottom side), 124 nets.

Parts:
BYP, BYP1, BYP2, BYP3: JUMPER-SMT_2_NO_SILK; SMT-JUMPER_2_NO_SILK
C1, C2, C3, C7, C9, C11, C12, C13, C15, C16, C21, C22, C23, C25, C26, C31, C32, C33, C35, C36: 0.1uF; 0603
C4, C5, C18, C19, C28, C29, C38, C39: 100uF; PANASONIC_D
C6, C14, C24, C34: 10uF; 0603
C8, C20, C30, C40: 1.0uF; 0603
C10, C17, C27, C37: 10nF; 0603
D1, D4, D7, D10: PRTR5V0U2F; SOT886
D2, D5, D8, D11: GREEN; LED-0603
D3, D6, D9, D12: Yellow; LED-0603
E1, E3, E5, E7: VHF; SMA-EDGE
E2, E4, E6, E8: GPS; SMA-EDGE
E$1, E$2, E$3, E$4: FIDUCIAL-1X2
E$5, E$6: FIDUCIAL-1.5X3
F1, F2, F3, F4: 6V/2A; 1210
FD1, FD2, FD3, FD4, FD5, FD6, FD7, FD8, FD9, FD10, FD11, FD12, FD13, FD14, FD15, FD16: FIDUCIAL1X2; FIDUCIAL-1X2
GPIO1, GPIO2, GPIO3, GPIO4: JUMPER-SMT_3_1-NC_TRACE_SILK; SMT-JUMPER_3_1-NC_TRACE_SILK
GPS, GPS1, GPS2, GPS3: U.FL
H1, H2, H3, H4, H7, H8, H9, H10, H13, H14, H15, H16, H19, H20, H21, H22: STAND-OFF
H5, H6, H11, H12, H17, H18, H23, H24: STAND-OFF-REFLOW-M2.5_1.5MM_TALL; STAND-OFF-REFLOW-M2.5
J1, J3, J5, J7: USB-C-16P-2LAYER-PADS
J2, J4, J6, J8: 1X04_NO_SILK
JP1, JP2, JP3, JP4: USB_SOLDER_PADS; USB-SOLDER-PADS
LOGO1, LOGO2, LOGO3, LOGO4, LOGO5, LOGO6, LOGO7, LOGO8: OSHW-LOGOM; OSHW-LOGO-M
Q1, Q3, Q6, Q8, Q10, Q12, Q14, Q16: SOT363_PHILIPS
Q2, Q4, Q5, Q7, Q9, Q11, Q13, Q15: 20V/4.2A/52mΩ/1.4W; SOT23-3
R1, R2, R7, R8, R17, R18, R31, R32: 5.1k; 0603
R3, R4, R13, R14, R27, R28, R37, R38: 100; 0603
R5, R6, R9, R11, R15, R16, R19, R21, R23, R25, R29, R30, R33, R35, R39, R40: 100k; 0603
R10, R12, R20, R22, R24, R26, R34, R36: 1M; 0603
RXI, RXI1, RXI2, RXI3: JUMPER-COMBO_2_NC_TRACE; COMBO-JUMPER_2_NC_TRACE
RX_LED, RX_LED1, RX_LED2, RX_LED3: JUMPER-SMT_2_NC_TRACE_SILK; SMT-JUMPER_2_NC_TRACE_SILK
TXO, TXO1, TXO2, TXO3: JUMPER-COMBO_2_NC_TRACE; COMBO-JUMPER_2_NC_TRACE
TX_LED, TX_LED1, TX_LED2, TX_LED3: JUMPER-SMT_2_NC_TRACE_SILK; SMT-JUMPER_2_NC_TRACE_SILK
U1, U4, U7, U10: CH340E_MSOP10; MSOP10
U2, U5, U8, U11: SWARM_M138_TRANSCEIVER_MAIN; M.2-SWARM-M138-A
U3, U6, U9, U12: 3.3V; SOT23-5
U$1, U$2, U$33, U$35, U$77, U$78, U$115, U$116: SPARKX-LOGO5; SPARKX-LARGE
U$3, U$38, U$79, U$117: VHF0
U$4, U$42, U$80, U$118: GPS0
U$5, U$76, U$114, U$152: VIN#__3#0V_MIN__5#0V_MAX0
U$6, U$73, U$111, U$149: PLEASE_CONSULT_THE_DOCUMENTATION0
U$7, U$52, U$90, U$128: #CH340_RXI#0
U$8, U$53, U$91, U$129: #CH340_RXI#341
U$9, U$54, U$92, U$130: #TXO#341
U$10, U$55, U$93, U$131: #TXO#342
U$11, U$56, U$94, U$132: #CH340_TXO#0
U$12, U$57, U$95, U$133: #CH340_TXO#341
U$13, U$58, U$96, U$134: #RXI#0
U$14, U$59, U$97, U$135: #RXI#1
U$15, U$61, U$99, U$137: #TX##RX##1
U$16, U$60, U$98, U$136: #TX##RX##0
U$17, U$63, U$101, U$139: #GPIO1_#2
U$18, U$65, U$103, U$141: V0
U$19, U$62, U$100, U$138: #GPIO1#0
U$20, U$64, U$102, U$140: #_GPIO1#2
U$21, U$22, U$43, U$44, U$81, U$82, U$119, U$120: #VIN#0
U$23, U$24, U$45, U$46, U$83, U$84, U$121, U$122: #GND#0
U$25, U$47, U$85, U$123: TX0
U$26, U$48, U$86, U$124: RX0
U$27, U$49, U$87, U$125: #TX_LED#0
U$28, U$50, U$88, U$126: #RX_LED#0
U$29, U$51, U$89, U$127: #BYPASS#0
U$30, U$66, U$104, U$142: G3
U$31, U$74, U$112, U$150: FOR_THE_PEAK_TRANSMIT_CURRENT1
U$32, U$75, U$113, U$151: NOT_COMPATIBLE_WITH_USB_2#02
U$34, U$39, U$69, U$70, U$107, U$108, U$145, U$146: SATELLITE_TRANSCEIVER_BREAKOUT0
U$36, U$67, U$105, U$143: D#2
U$37, U$68, U$106, U$144: D#1
U$40, U$41, U$71, U$72, U$109, U$110, U$147, U$148: SWARM_M1381
VCC, VCC1, VCC2, VCC3: TEST-POINT3X5; PAD.03X.05
VHF, VHF1, VHF2, VHF3: U.FL

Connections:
3.3V: C8.1, R5.2, U3.5
3.3V1: C20.1, R15.2, U6.5
3.3V2: C30.1, R29.2, U9.5
3.3V3: C40.1, R39.2, U12.5
CH340_RXI: D2.C, TXO.2, TXO.4, U1.9
CH340_RXI1: D5.C, TXO1.2, TXO1.4, U4.9
CH340_RXI2: D8.C, TXO2.2, TXO2.4, U7.9
CH340_RXI3: D11.C, TXO3.2, TXO3.4, U10.9
CH340_TXO: D3.C, RXI.1, RXI.3, U1.8
CH340_TXO1: D6.C, RXI1.1, RXI1.3, U4.8
CH340_TXO2: D9.C, RXI2.1, RXI2.3, U7.8
CH340_TXO3: D12.C, RXI3.1, RXI3.3, U10.8
D+: D1.6, U1.1
D+1: D4.6, U4.1
D+2: D7.6, U7.1
D+3: D10.6, U10.1
D+_IN: D1.1, J1.A6, J1.B6, JP1.D+
D+_IN1: D4.1, J3.A6, J3.B6, JP2.D+
D+_IN2: D7.1, J5.A6, J5.B6, JP3.D+
D+_IN3: D10.1, J7.A6, J7.B6, JP4.D+
D-: D1.4, U1.2
D-1: D4.4, U4.2
D-2: D7.4, U7.2
D-3: D10.4, U10.2
D-_IN: D1.3, J1.A7, J1.B7, JP1.D-
D-_IN1: D4.3, J3.A7, J3.B7, JP2.D-
D-_IN2: D7.3, J5.A7, J5.B7, JP3.D-
D-_IN3: D10.3, J7.A7, J7.B7, JP4.D-
GND: C1.2, C2.2, C3.2, C4.-, C5.-, C6.2, C7.2, C8.2, C9.2, C10.2, D1.2, E1.GND@0, E1.GND@1, E1.GND@2, E1.GND@3, E2.GND@0, E2.GND@1, E2.GND@2, E2.GND@3, GPS.1, GPS.2, H5.1, H6.1, J1.GND, J1.GND2, J1.SHLD1, J1.SHLD2, J1.SHLD3, J1.SHLD4, J2.1, JP1.GND, R1.1, R2.1, R6.1, R21.1, R22.1, R23.1, R24.1, U1.3, U2.4, U2.9, U2.15, U2.18, U2.21, U2.26, U2.27, U2.29, U2.34, U2.35, U2.37, U2.40, U2.43, U2.50, U2.A1, U2.A2, U3.2, VHF.1, VHF.2
GND1: C11.2, C12.2, C13.2, C14.2, C15.2, C16.2, C17.2, C18.-, C19.-, C20.2, D4.2, E3.GND@0, E3.GND@1, E3.GND@2, E3.GND@3, E4.GND@0, E4.GND@1, E4.GND@2, E4.GND@3, GPS1.1, GPS1.2, H11.1, H12.1, J3.GND, J3.GND2, J3.SHLD1, J3.SHLD2, J3.SHLD3, J3.SHLD4, J4.1, JP2.GND, R7.1, R8.1, R9.1, R10.1, R11.1, R12.1, R16.1, U4.3, U5.4, U5.9, U5.15, U5.18, U5.21, U5.26, U5.27, U5.29, U5.34, U5.35, U5.37, U5.40, U5.43, U5.50, U5.A1, U5.A2, U6.2, VHF1.1, VHF1.2
GND2: C21.2, C22.2, C23.2, C24.2, C25.2, C26.2, C27.2, C28.-, C29.-, C30.2, D7.2, E5.GND@0, E5.GND@1, E5.GND@2, E5.GND@3, E6.GND@0, E6.GND@1, E6.GND@2, E6.GND@3, GPS2.1, GPS2.2, H17.1, H18.1, J5.GND, J5.GND2, J5.SHLD1, J5.SHLD2, J5.SHLD3, J5.SHLD4, J6.1, JP3.GND, R17.1, R18.1, R19.1, R20.1, R25.1, R26.1, R30.1, U7.3, U8.4, U8.9, U8.15, U8.18, U8.21, U8.26, U8.27, U8.29, U8.34, U8.35, U8.37, U8.40, U8.43, U8.50, U8.A1, U8.A2, U9.2, VHF2.1, VHF2.2
GND3: C31.2, C32.2, C33.2, C34.2, C35.2, C36.2, C37.2, C38.-, C39.-, C40.2, D10.2, E7.GND@0, E7.GND@1, E7.GND@2, E7.GND@3, E8.GND@0, E8.GND@1, E8.GND@2, E8.GND@3, GPS3.1, GPS3.2, H23.1, H24.1, J7.GND, J7.GND2, J7.SHLD1, J7.SHLD2, J7.SHLD3, J7.SHLD4, J8.1, JP4.GND, R31.1, R32.1, R33.1, R34.1, R35.1, R36.1, R40.1, U10.3, U11.4, U11.9, U11.15, U11.18, U11.21, U11.26, U11.27, U11.29, U11.34, U11.35, U11.37, U11.40, U11.43, U11.50, U11.A1, U11.A2, U12.2, VHF3.1, VHF3.2
GPIO1: GPIO1.2, J2.3, U2.42
GPIO2: GPIO2.2, J4.3, U5.42
GPIO3: GPIO3.2, J6.3, U8.42
GPIO4: GPIO4.2, J8.3, U11.42
GPS: E2.SIG, GPS.FEED
GPS1: E4.SIG, GPS1.FEED
GPS2: E6.SIG, GPS2.FEED
GPS3: E8.SIG, GPS3.FEED
unnamed: J3.B5, R7.2
unnamed: J1.B5, R1.2
unnamed: J1.A5, R2.2
unnamed: J3.A5, R8.2
unnamed: Q1.2, Q1.5, Q1.6, R21.2
unnamed: C9.1, RX_LED.1, TX_LED.2, U1.10
unnamed: R4.1, RX_LED.2
unnamed: Q6.2, Q6.5, Q6.6, R9.2
unnamed: D2.A, R3.2
unnamed: D3.A, R4.2
unnamed: Q5.1, Q6.3, R10.2
unnamed: R3.1, TX_LED.1
unnamed: Q1.3, Q2.1, R22.2
unnamed: GPIO1.3, R5.1
unnamed: Q3.2, Q3.5, Q3.6, R23.2
unnamed: GPIO1.1, R6.2
unnamed: Q8.2, Q8.5, Q8.6, R11.2
unnamed: Q7.1, Q8.3, R12.2
unnamed: C16.1, RX_LED1.1, TX_LED1.2, U4.10
unnamed: D5.A, R13.2
unnamed: D6.A, R14.2
unnamed: R14.1, RX_LED1.2
unnamed: R13.1, TX_LED1.1
unnamed: GPIO2.3, R15.1
unnamed: GPIO2.1, R16.2
unnamed: J5.B5, R17.2
unnamed: J5.A5, R18.2
unnamed: Q3.3, Q4.1, R24.2
unnamed: Q10.2, Q10.5, Q10.6, R19.2
unnamed: Q9.1, Q10.3, R20.2
unnamed: Q12.2, Q12.5, Q12.6, R25.2
unnamed: Q11.1, Q12.3, R26.2
unnamed: C26.1, RX_LED2.1, TX_LED2.2, U7.10
unnamed: D8.A, R27.2
unnamed: D9.A, R28.2
unnamed: R28.1, RX_LED2.2
unnamed: R27.1, TX_LED2.1
unnamed: GPIO3.3, R29.1
unnamed: GPIO3.1, R30.2
unnamed: J7.B5, R31.2
unnamed: J7.A5, R32.2
unnamed: Q14.2, Q14.5, Q14.6, R33.2
unnamed: Q13.1, Q14.3, R34.2
unnamed: Q16.2, Q16.5, Q16.6, R35.2
unnamed: Q15.1, Q16.3, R36.2
unnamed: C36.1, RX_LED3.1, TX_LED3.2, U10.10
unnamed: D11.A, R37.2
unnamed: D12.A, R38.2
unnamed: R38.1, RX_LED3.2
unnamed: R37.1, TX_LED3.1
unnamed: GPIO4.3, R39.1
unnamed: GPIO4.1, R40.2
RXI: RXI.2, RXI.4, U2.11
RXI1: RXI1.2, RXI1.4, U5.11
RXI2: RXI2.2, RXI2.4, U8.11
RXI3: RXI3.2, RXI3.4, U11.11
TX/!RX!: J2.4, U2.17
TX/!RX!1: J4.4, U5.17
TX/!RX!2: J6.4, U8.17
TX/!RX!3: J8.4, U11.17
TXO: TXO.1, TXO.3, U2.13
TXO1: TXO1.1, TXO1.3, U5.13
TXO2: TXO2.1, TXO2.3, U8.13
TXO3: TXO3.1, TXO3.3, U11.13
VCC: C3.1, C4.+, C5.+, C6.1, C7.1, Q1.4, Q2.2, Q3.4, Q4.2, U2.2, U2.39, U2.41, U2.52, U3.1, U3.3, VCC.1
VCC1: C13.1, C14.1, C15.1, C18.+, C19.+, Q5.2, Q6.4, Q7.2, Q8.4, U5.2, U5.39, U5.41, U5.52, U6.1, U6.3, VCC1.1
VCC2: C23.1, C24.1, C25.1, C28.+, C29.+, Q9.2, Q10.4, Q11.2, Q12.4, U8.2, U8.39, U8.41, U8.52, U9.1, U9.3, VCC2.1
VCC3: C33.1, C34.1, C35.1, C38.+, C39.+, Q13.2, Q14.4, Q15.2, Q16.4, U11.2, U11.39, U11.41, U11.52, U12.1, U12.3, VCC3.1
VHF: E1.SIG, VHF.FEED
VHF1: E3.SIG, VHF1.FEED
VHF2: E5.SIG, VHF2.FEED
VHF3: E7.SIG, VHF3.FEED
VIN: C2.1, J2.2, Q3.1, Q4.3
VIN1: C12.1, J4.2, Q7.3, Q8.1
VIN2: C22.1, J6.2, Q11.3, Q12.1
VIN3: C32.1, J8.2, Q15.3, Q16.1
V_USB: BYP.2, D1.5, F1.1, J1.VBUS1, J1.VBUS2, JP1.VBUS
V_USB1: BYP1.2, D4.5, F2.1, J3.VBUS1, J3.VBUS2, JP2.VBUS
V_USB2: BYP2.2, D7.5, F3.1, J5.VBUS1, J5.VBUS2, JP3.VBUS
V_USB3: BYP3.2, D10.5, F4.1, J7.VBUS1, J7.VBUS2, JP4.VBUS
V_USB_1: BYP1.1, C11.1, C17.1, F2.2, Q5.3, Q6.1, U4.7
V_USB_2: BYP.1, C1.1, C10.1, F1.2, Q1.1, Q2.3, U1.7
V_USB_3: BYP2.1, C21.1, C27.1, F3.2, Q9.3, Q10.1, U7.7
V_USB_4: BYP3.1, C31.1, C37.1, F4.2, Q13.3, Q14.1, U10.7

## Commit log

2022-03-10 Add x02 Hardware
    [Satellite_Transceiver_Breakout__Swarm_M138-Panel.GBL, Satellite_Transceiver_Breakout__Swarm_M138-Panel.GBO, Satellite_Transceiver_Breakout__Swarm_M138-Panel.GB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]
2022-03-13 Update NC jumper links
    [Satellite_Transceiver_Breakout__Swarm_M138-Panel.brd, Satellite_Transceiver_Breakout__Swarm_M138.brd, Satellite_Transceiver_Breakout__Swarm_M138.sch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]
2022-03-15 Replace 3.3V Reg with AP2112K
    [Satellite_Transceiver_Breakout__Swarm_M138-Panel.brd, Satellite_Transceiver_Breakout__Swarm_M138.brd, Satellite_Transceiver_Breakout__Swarm_M138.sch]
2022-03-24 Add ignore. Add ground plate.
    [Ground Plate.brd, Ground Plate.sch]
2022-03-25 Add revised ground plate
    [Ground Plate.brd, Ground Plate.sch]
2022-03-25 Create Ground Plate.zip
2022-03-25 Combining ground plate versions
    [Ground Plate.brd, Ground Plate.sch]
2022-03-25 Adding gerbers
2022-05-18 Add Ground Plane dimensions
2022-05-20 Updates for x03 PCB - move standoffs by 0.6mm and add route-out gaps in panel
    [Satellite_Transceiver_Breakout__Swarm_M138-Panel.brd, Satellite_Transceiver_Breakout__Swarm_M138.brd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]
2022-08-02 Add BOM
    [Satellite_Transceiver_Breakout__Swarm_M138.csv, bom_output.csv]

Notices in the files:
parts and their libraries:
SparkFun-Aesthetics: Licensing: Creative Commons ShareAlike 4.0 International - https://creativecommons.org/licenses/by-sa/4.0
